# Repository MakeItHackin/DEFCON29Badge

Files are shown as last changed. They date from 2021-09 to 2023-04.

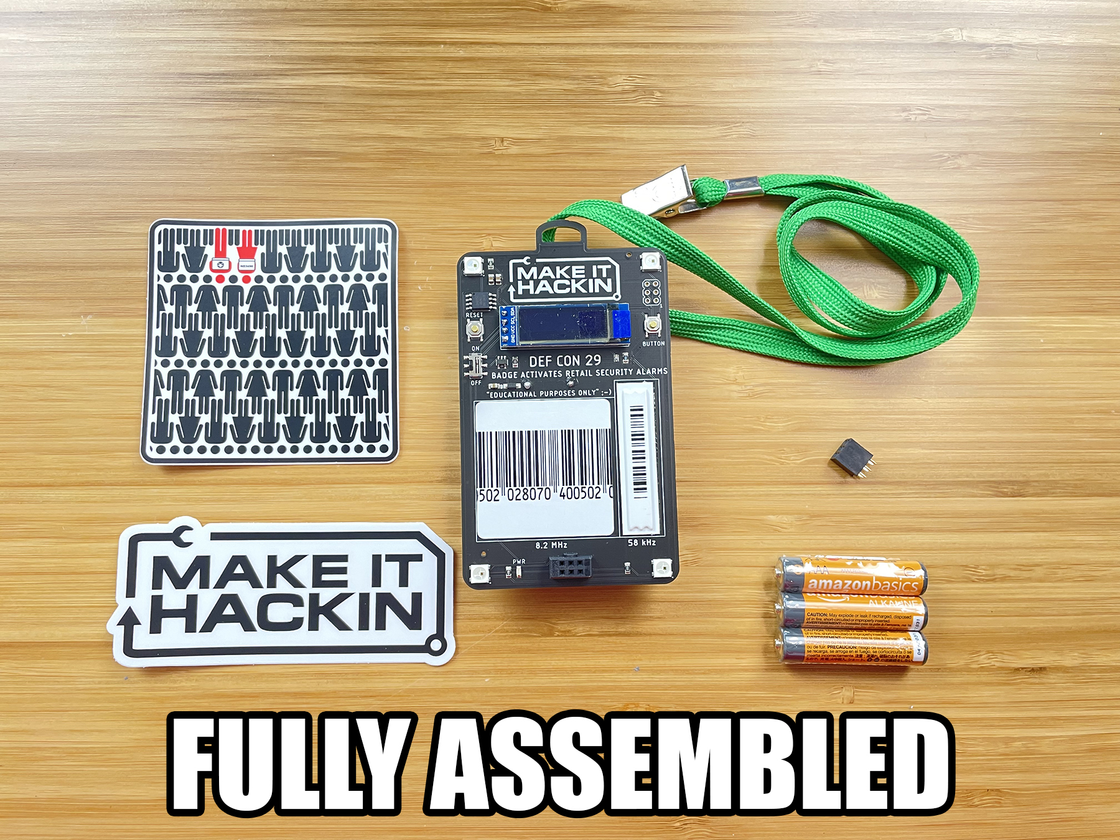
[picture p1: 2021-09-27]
Pictures/FullyAssembled/fa pic.jpg

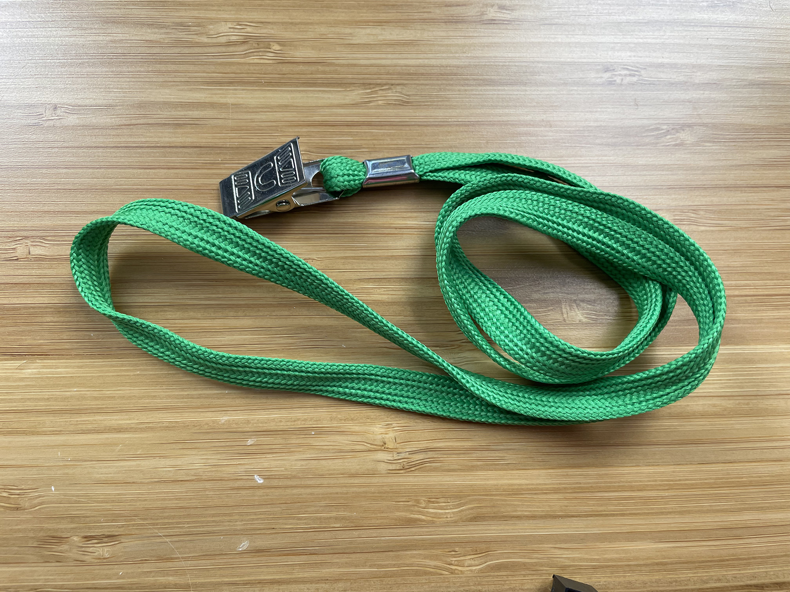
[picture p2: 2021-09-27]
Pictures/FullyAssembled/IMG_9313.jpeg

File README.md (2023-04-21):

# DC 29 Badge and SAO
==========================================================

Purchase Fully Assembled Badge or Kit Here:  
https://www.tindie.com/products/makeithackin/makeithackin-def-con-29-electronic-badge/

Unboxing, Reviewing, and Programming a Fully-Assembled Badge:  
https://youtu.be/G82_usjS0wA

Assembling the badge kit:  
https://youtu.be/OIYtvjFRpec

I'll update this readme as time goes on, but yeah... this is my first official MakeItHackin unoffical DEF CON badge.

Badges will feature an ATTiny85 Microcontroller, OLED Display, RGB LEDs, and a SAO connector for all your shitty add-ons.

They will also include two security tags (applied in those blank spots).  One is for Checkpoint systems (8.2 MHz) and one is for Sensormatic systems (58 kHz).  Take your badge into any retail store and set off their alarms!  (just kidding, don't do that.)

It was difficult to think of a shape for the outline and I wanted to get them ordered ASAP, so I made the badge in the shape of a credit card to relate to the retail security theme.  

Hack the Planet

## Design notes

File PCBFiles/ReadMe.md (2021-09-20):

These are the Gerber Files used to make the PCBs.  Make your own!
The Eagle files are also included (.sch and .brd) for the Badge and SAO

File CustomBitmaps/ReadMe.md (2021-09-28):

Here's how to create a custom Bitmap for your MakeItHackin Badge.  This requires you to reprogram your badge, so you'll need an AVR programmer and a way to upload the code (Arduino IDE can do it)

I briefly cover this process in the YouTube tutorial: https://youtu.be/G82_usjS0wA

Create a bitmap that is 128x32 pixels.  You can use the photoshop template in this folder, or rework one of the bitmaps included.  When I save the template as a bitmap in photoshop I use the following settings for bitmap: Windows / 24 bit.

Next, convert bitmap to code: https://javl.github.io/image2cpp/
Use the following settings:
Background color: black
Invert image colors: yes
Canvas size: 128x32
Code output format: Arduino
Draw mode: Vertical - 1 bit per pixel

Then copy the output code and paste it into the variable  "customBitmap", which looks like a big array of HEX.  It'll be the last one of these you see in the code.  Make sure to replace the previous code inside that variable.

Finally, change the variable "badgeType" to the value of 8.  This will tell the code to display the customBitmap screen.

That's it!

Enjoy!

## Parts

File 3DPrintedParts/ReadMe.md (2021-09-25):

I created some 3d printed parts to help me assemble hundreds of badges.  They are not necessary if you're building one or two badges, but helpful for multiple.  Maybe they'll give you some ideas as well.  They were designed in Fusion 360 and printed on a Prusa Mini+

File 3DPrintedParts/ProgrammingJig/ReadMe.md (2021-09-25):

These are parts I made for my Programming Jig.

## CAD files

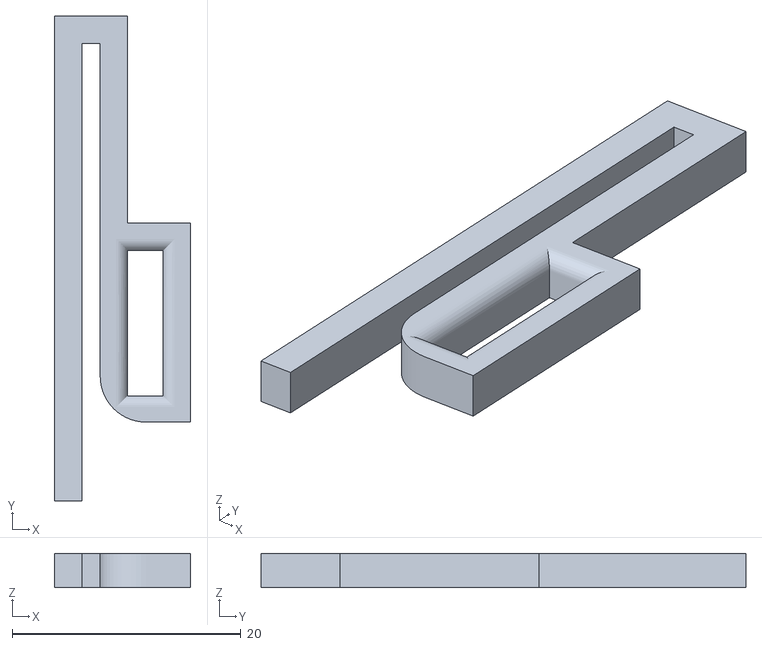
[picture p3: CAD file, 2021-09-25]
3DPrintedParts/OLEDSpacer v7.stl
11.9 x 42.4 x 3.00

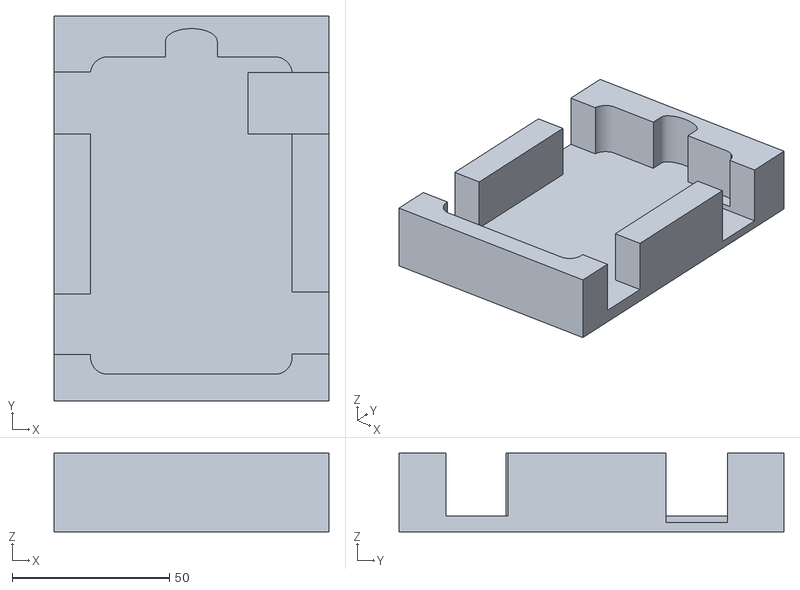
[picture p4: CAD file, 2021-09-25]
3DPrintedParts/ProgrammingJig/programmerJig_thickness1-5 v2.stl
87.5 x 122.6 x 25.0

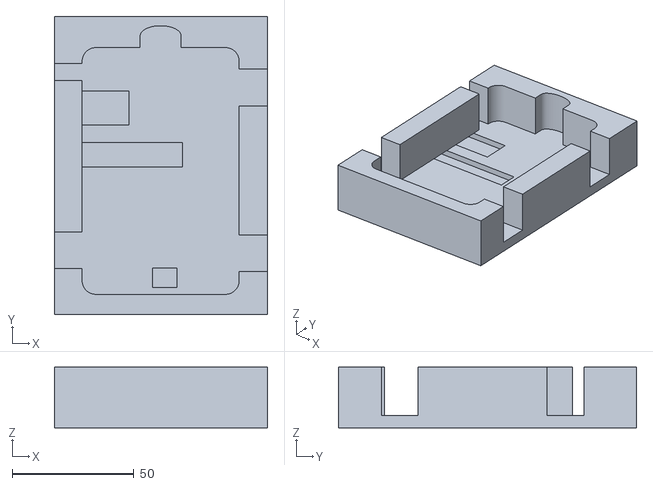
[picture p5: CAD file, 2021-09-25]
3DPrintedParts/TestingJig/testerJig_thickness2 v2.stl
87.5 x 122.6 x 25.0

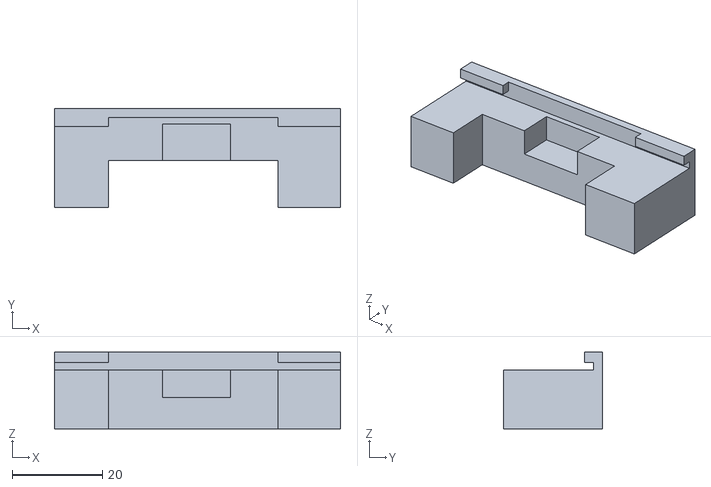
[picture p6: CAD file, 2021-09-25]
3DPrintedParts/BatterySpacer v6.stl
63.3 x 22.0 x 17.0

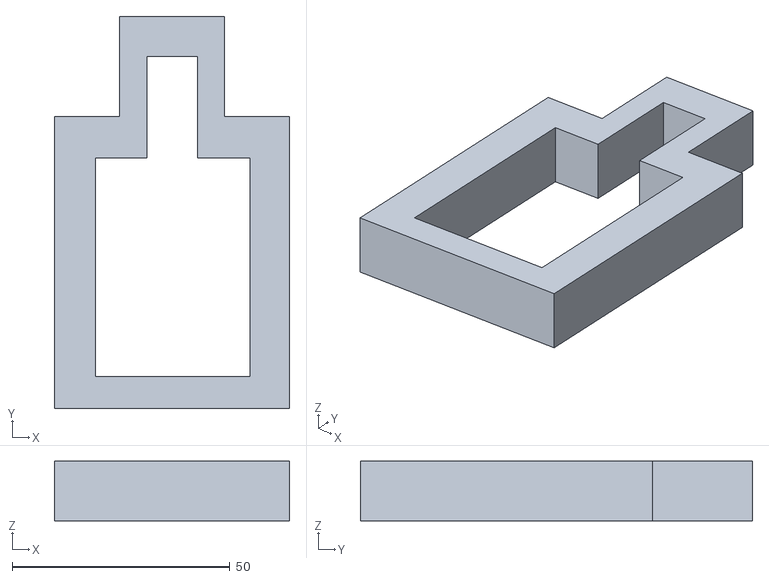
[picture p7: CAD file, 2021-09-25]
3DPrintedParts/ProgrammingJig/spacerv2 v1.stl
54.0 x 90.0 x 13.7

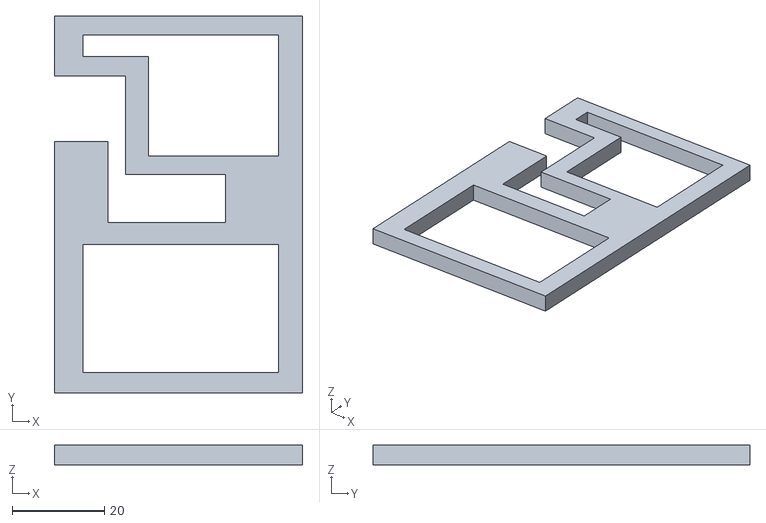
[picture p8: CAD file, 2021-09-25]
3DPrintedParts/TestingJig/testerJigSpacer v4.stl
53.9 x 81.8 x 4.30

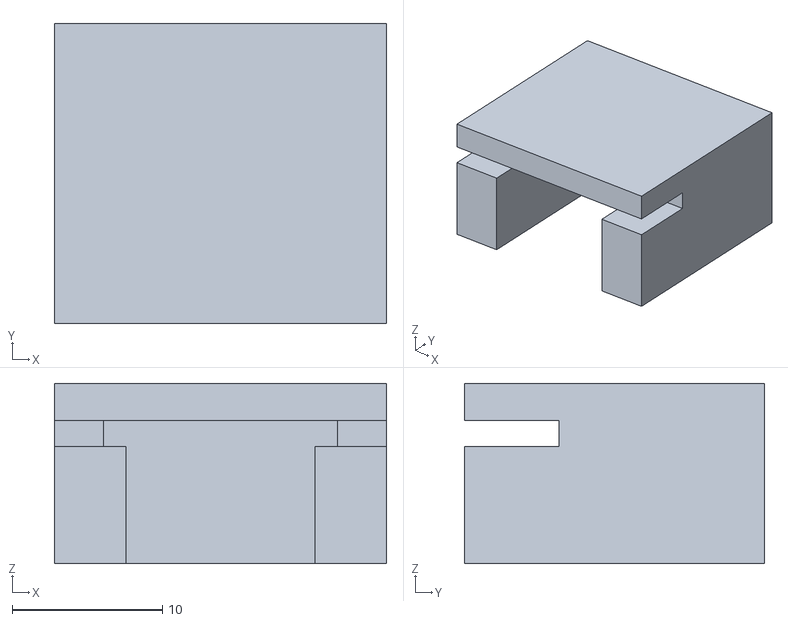
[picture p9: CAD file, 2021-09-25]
3DPrintedParts/SAOSpacer_TOP v6.stl
22.1 x 20.0 x 12.0

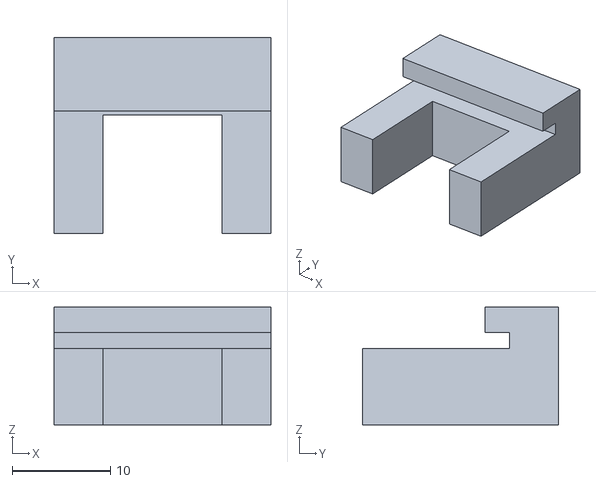
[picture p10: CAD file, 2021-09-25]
3DPrintedParts/SAOSpacer_redo v9.stl
22.1 x 20.0 x 12.0

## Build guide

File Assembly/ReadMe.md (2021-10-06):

Here are some files helpful for assembling the badge.  Watch the step-by-step video here:  https://youtu.be/OIYtvjFRpec

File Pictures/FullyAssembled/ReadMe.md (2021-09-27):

These are the pictures for the Fully Assembled Version

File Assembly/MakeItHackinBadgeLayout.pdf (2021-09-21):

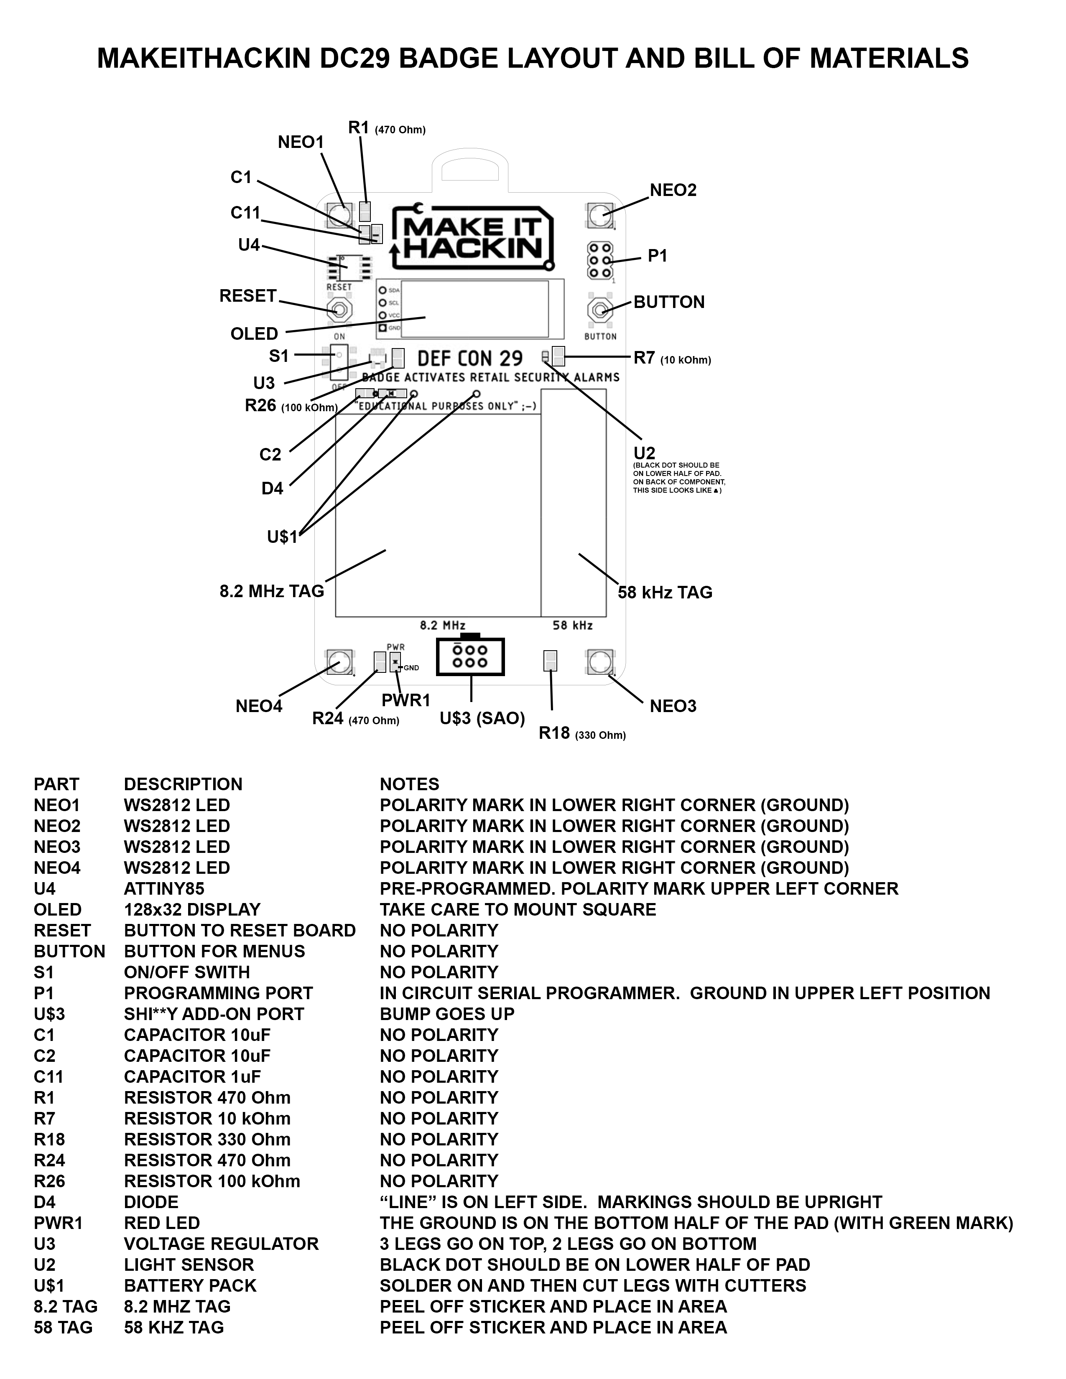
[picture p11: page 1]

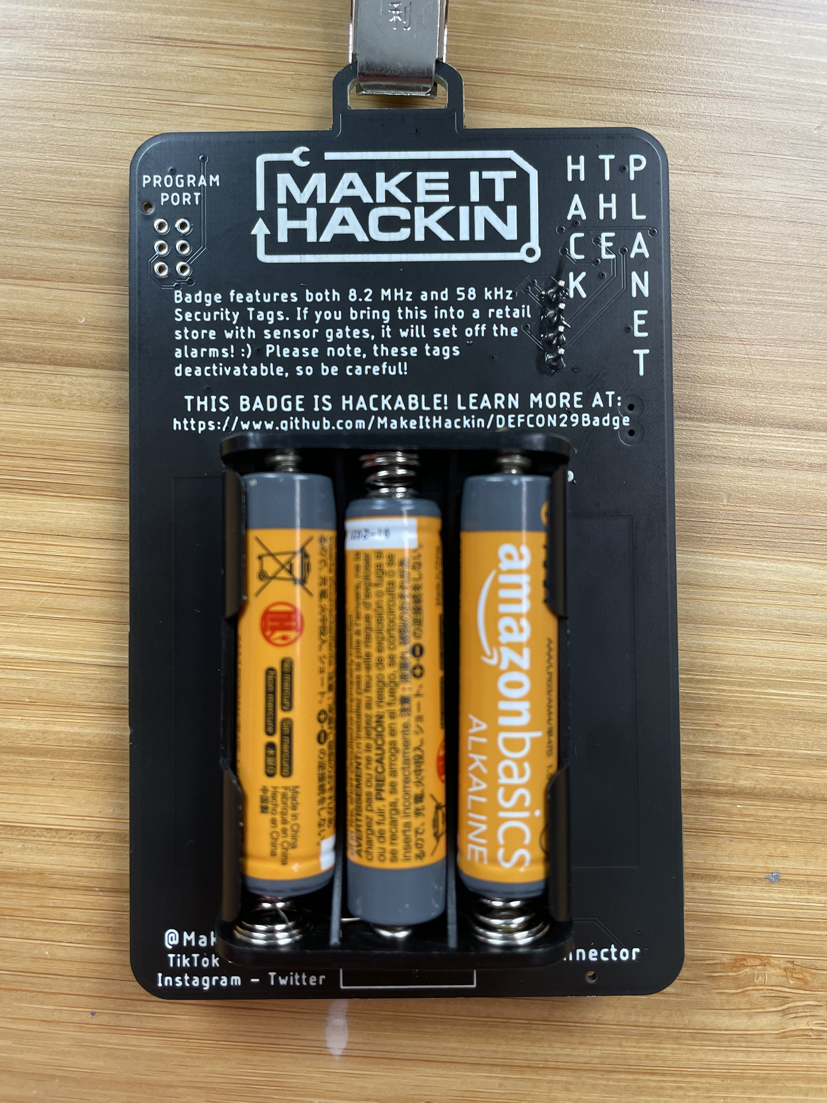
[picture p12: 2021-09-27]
Pictures/FullyAssembled/back.jpg

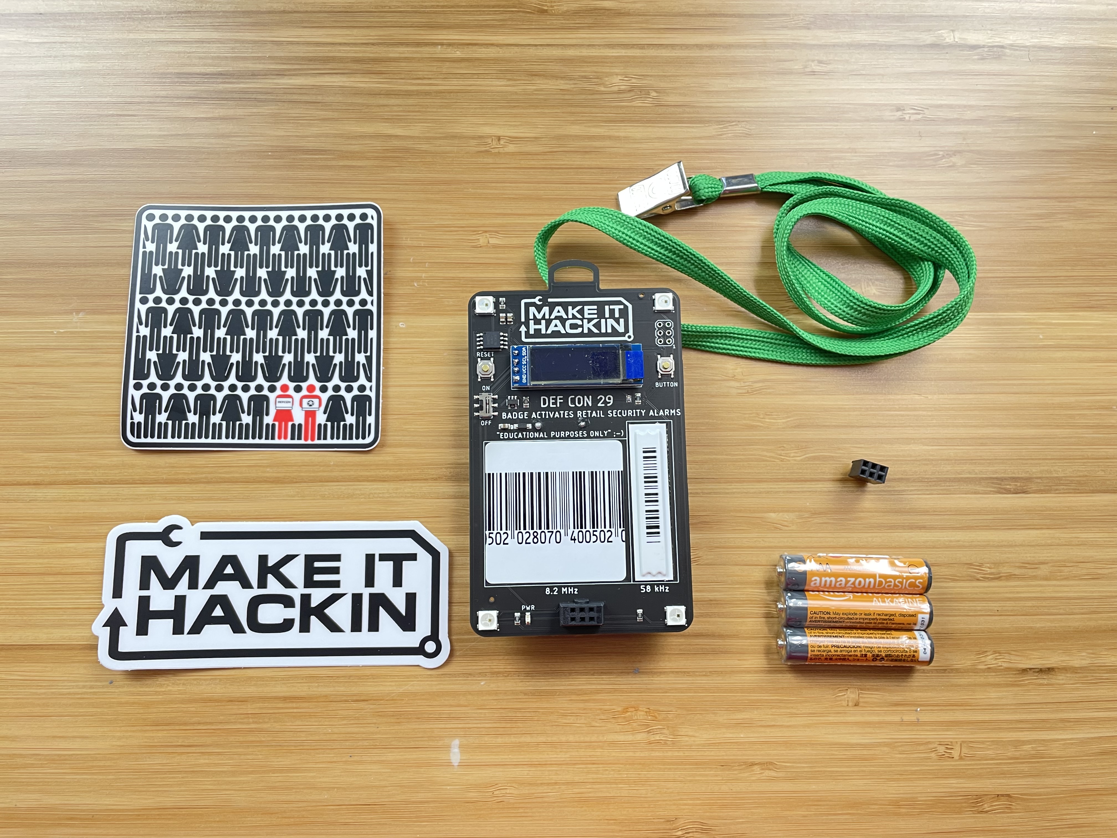
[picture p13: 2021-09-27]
Pictures/FullyAssembled/IMG_9314.jpeg

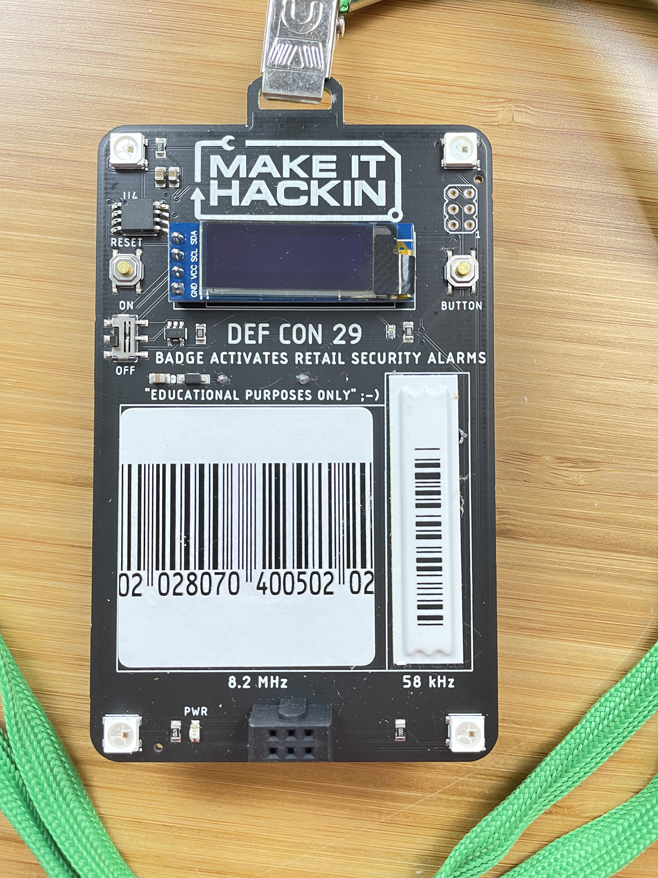
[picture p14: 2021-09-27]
Pictures/FullyAssembled/IMG_9297.jpeg

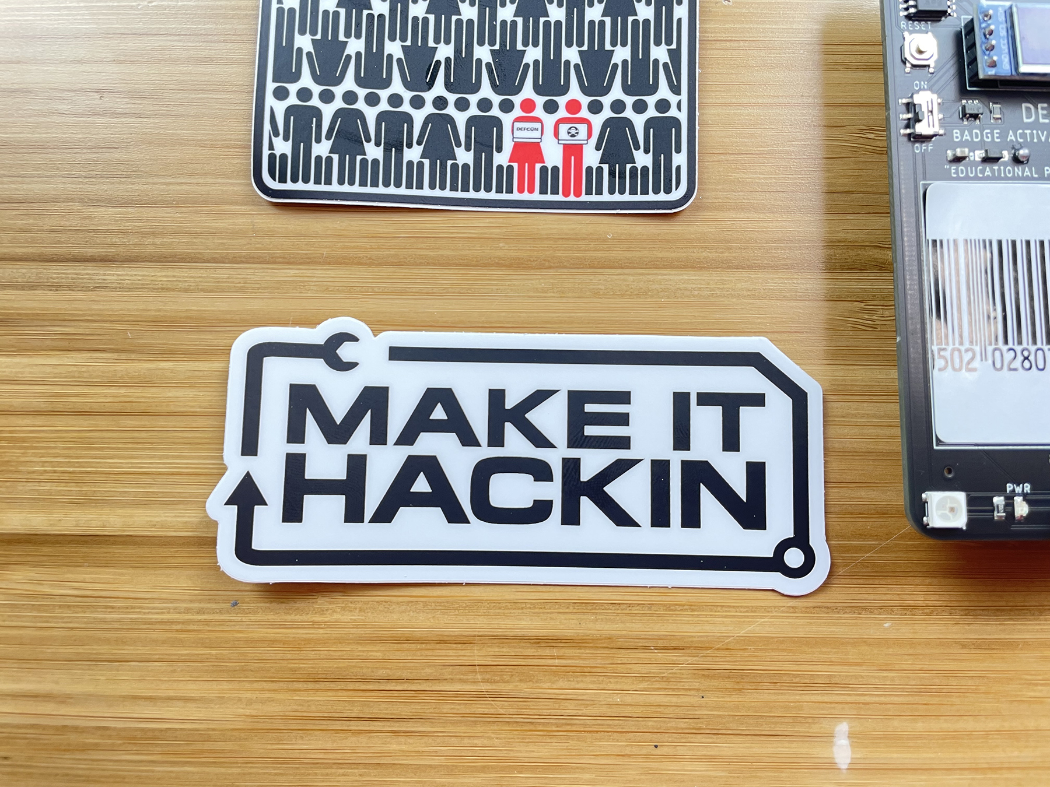
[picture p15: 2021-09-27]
Pictures/FullyAssembled/IMG_9316.jpeg

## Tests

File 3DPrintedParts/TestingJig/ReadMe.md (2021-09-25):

These are parts I printed for my Testing Jig

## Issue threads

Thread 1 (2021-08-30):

Code for IC

adradloff, 2021-08-30:
When will the code for the IC be posted?  I ordered the parts for my PCB I received and am starting to put it all together.  Thanks.

PS. hopefully I solder that ATTINY85-20MUR on properly,  that was a pita.

MakeItHackin, 2021-08-31:
haha... yup.  QFNs are not fun.  i havent commented a lot of the code yet, but i'll go ahead and put it up!  i might switch it out later with more comments, but the functionality "probably" will not change.

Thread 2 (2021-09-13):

schematic, and the markings on the PCB

g0Idfinger, 2021-09-13:
Do you have a schematic and marking as to which component goes where on the board?  The rest of my components should be in this weekend and I would love to get this put together.  Thanks for your help and creating this great badge!

MakeItHackin, 2021-09-14:
hey there, this info will be posted within the next two weeks when I prepare the instructions for the people who ordered the kits

MakeItHackin, 2021-09-20:
> Do you have a schematic and marking as to which component goes where on the board? The rest of my components should be in this weekend and I would love to get this put together. Thanks for your help and creating this great badge!

hey, i just uploaded schematic and board layouts to the "Assembly" folder

g0Idfinger, 2021-09-21:
Thanks, I got it together and the IC is programmed, the display comes up and says press button to test components, and does nothing, so I guess I have some testing to do.

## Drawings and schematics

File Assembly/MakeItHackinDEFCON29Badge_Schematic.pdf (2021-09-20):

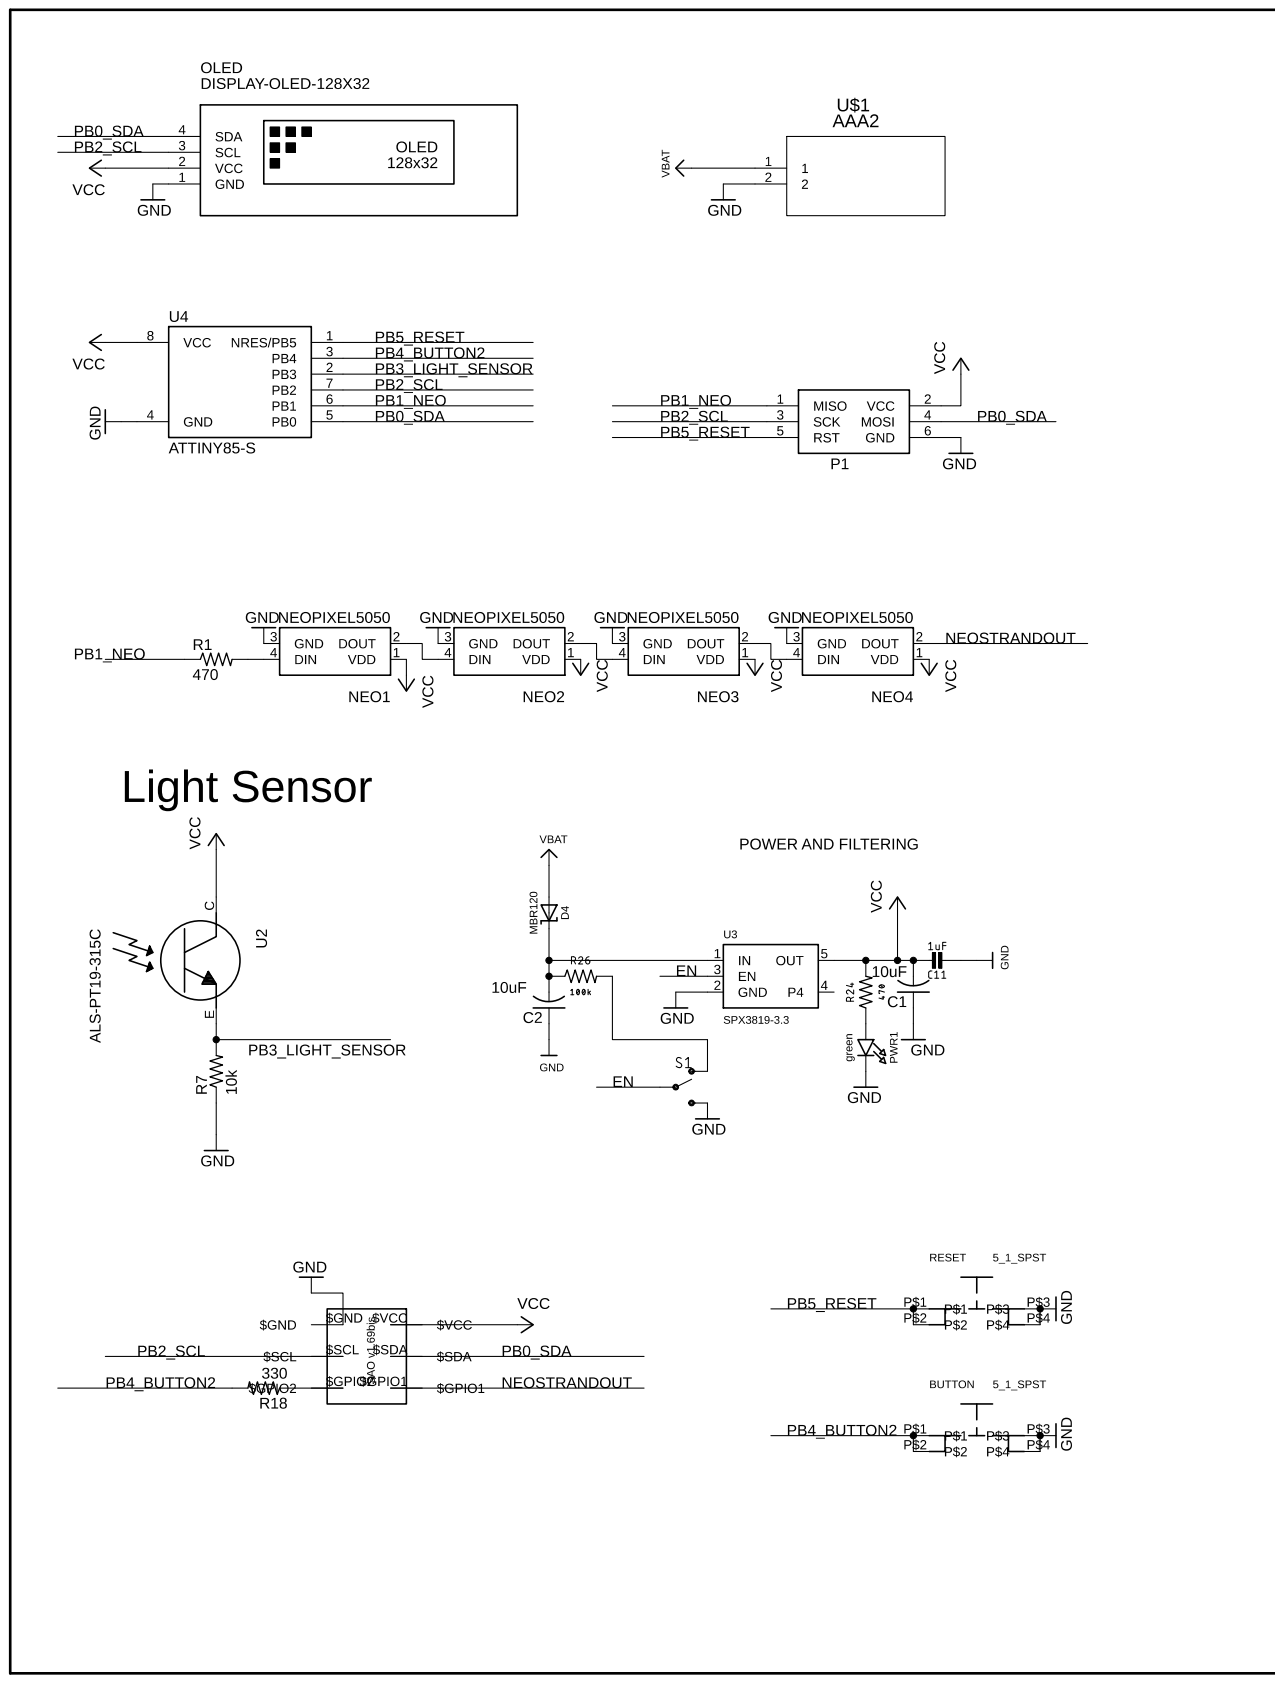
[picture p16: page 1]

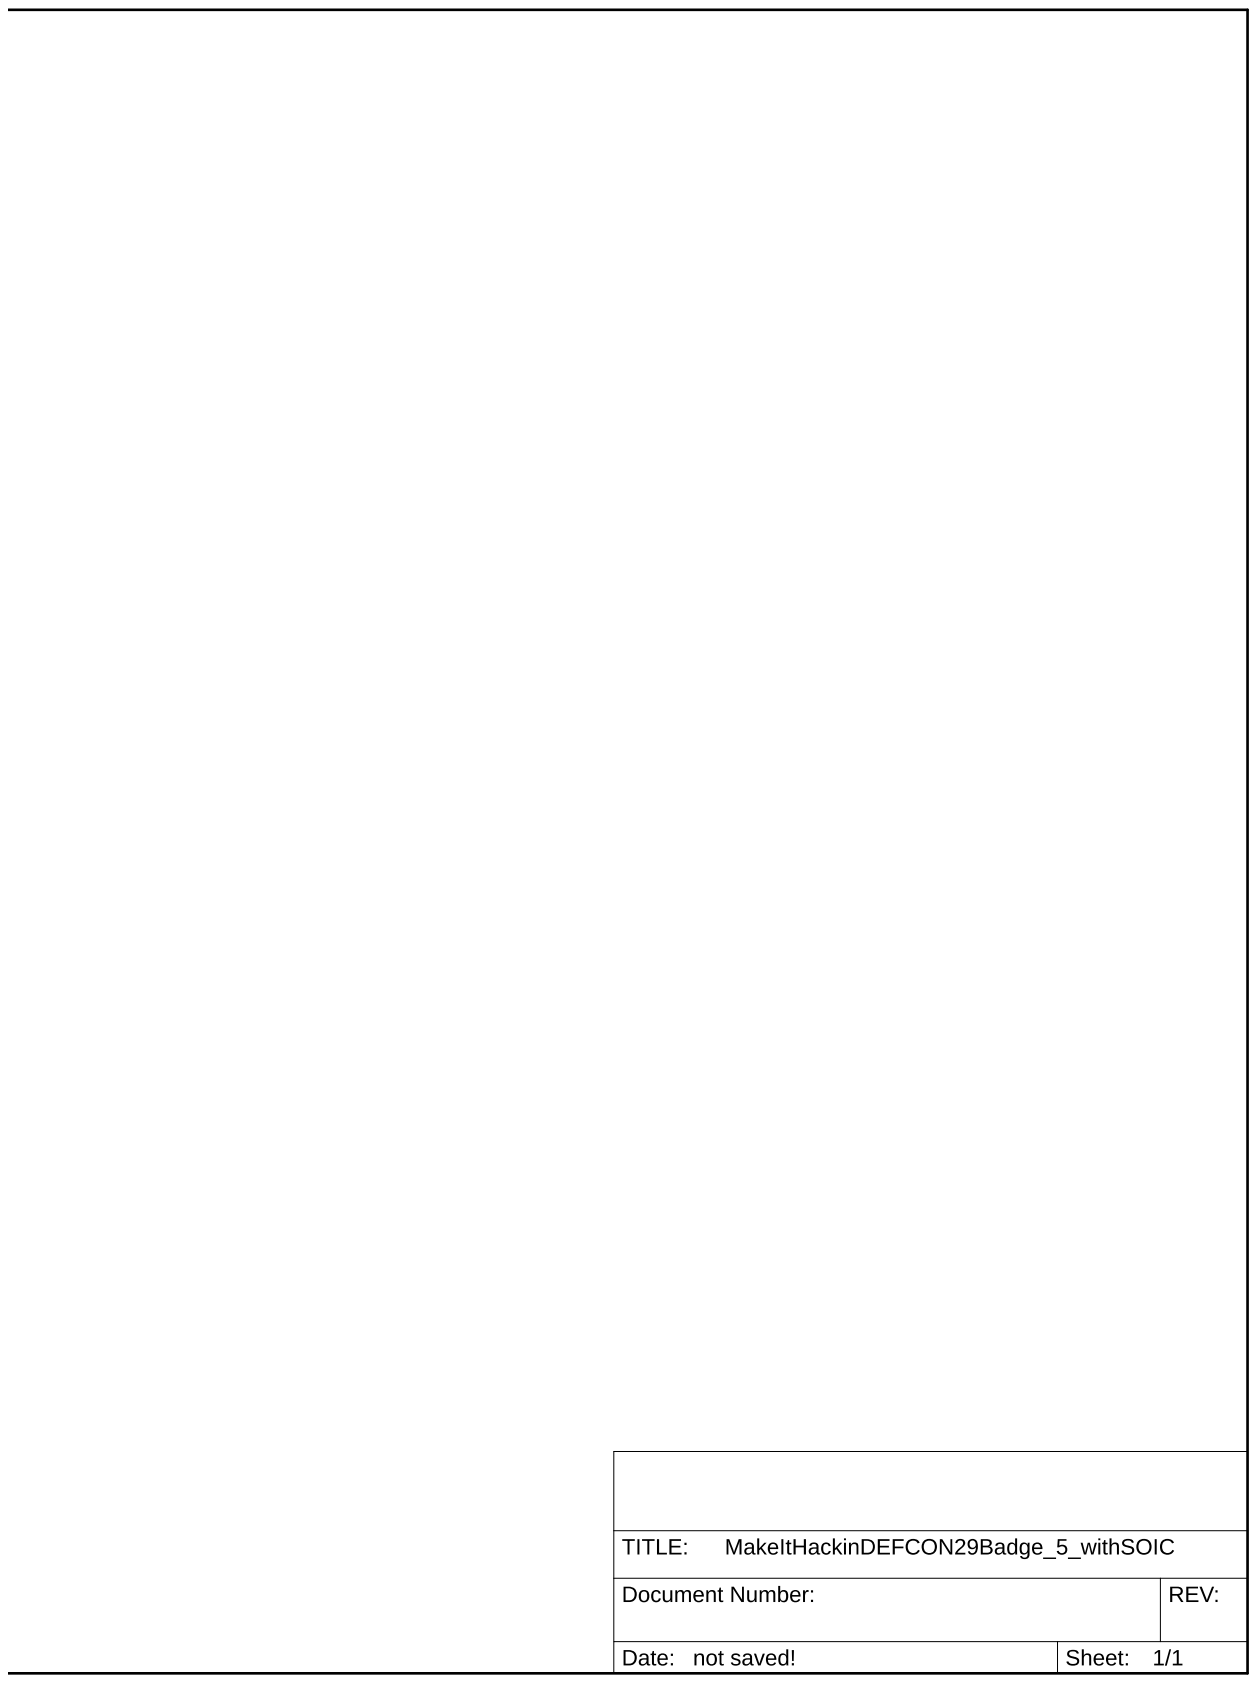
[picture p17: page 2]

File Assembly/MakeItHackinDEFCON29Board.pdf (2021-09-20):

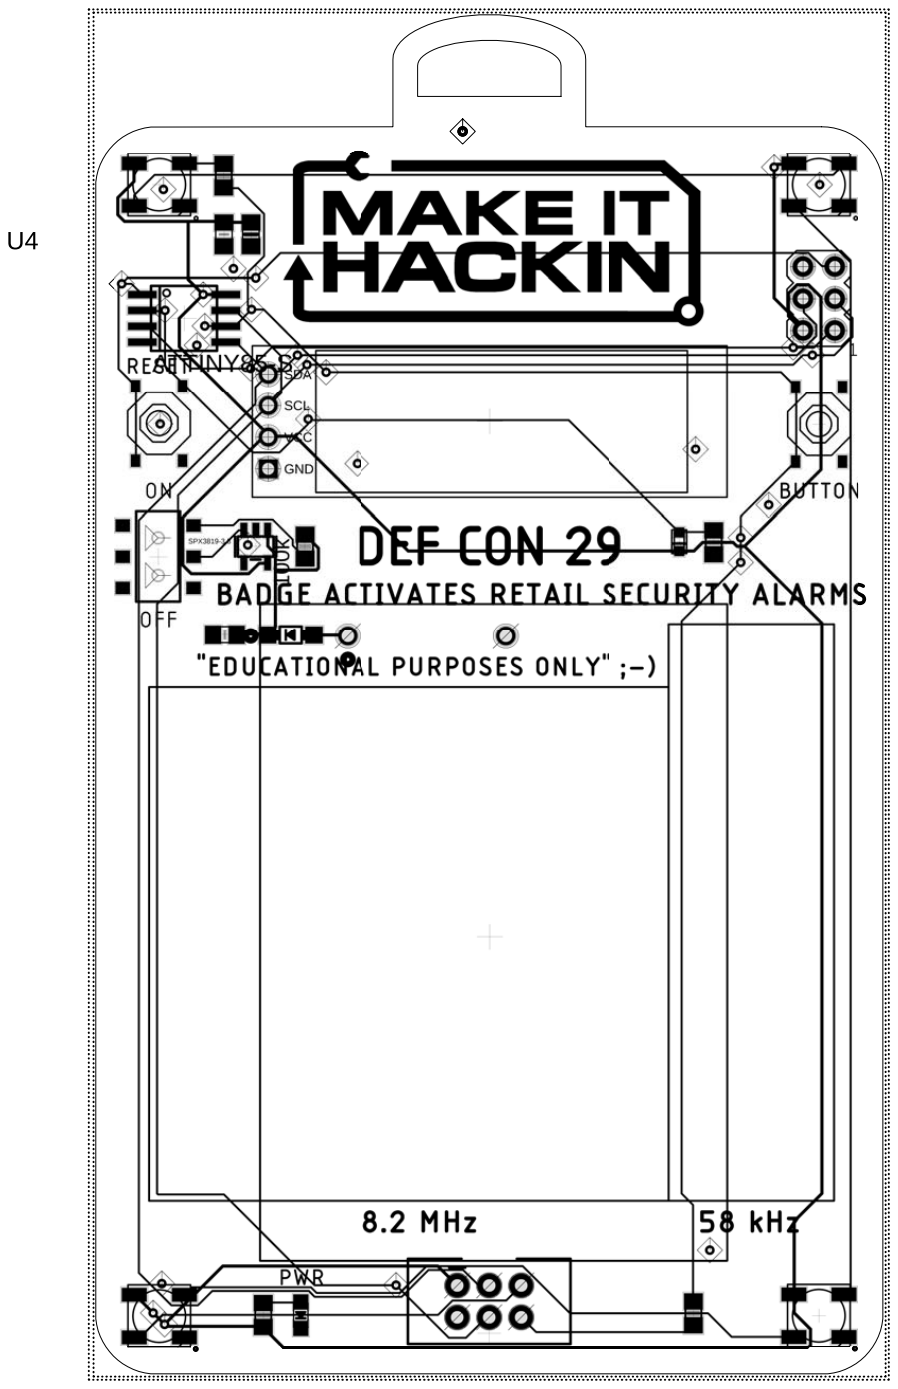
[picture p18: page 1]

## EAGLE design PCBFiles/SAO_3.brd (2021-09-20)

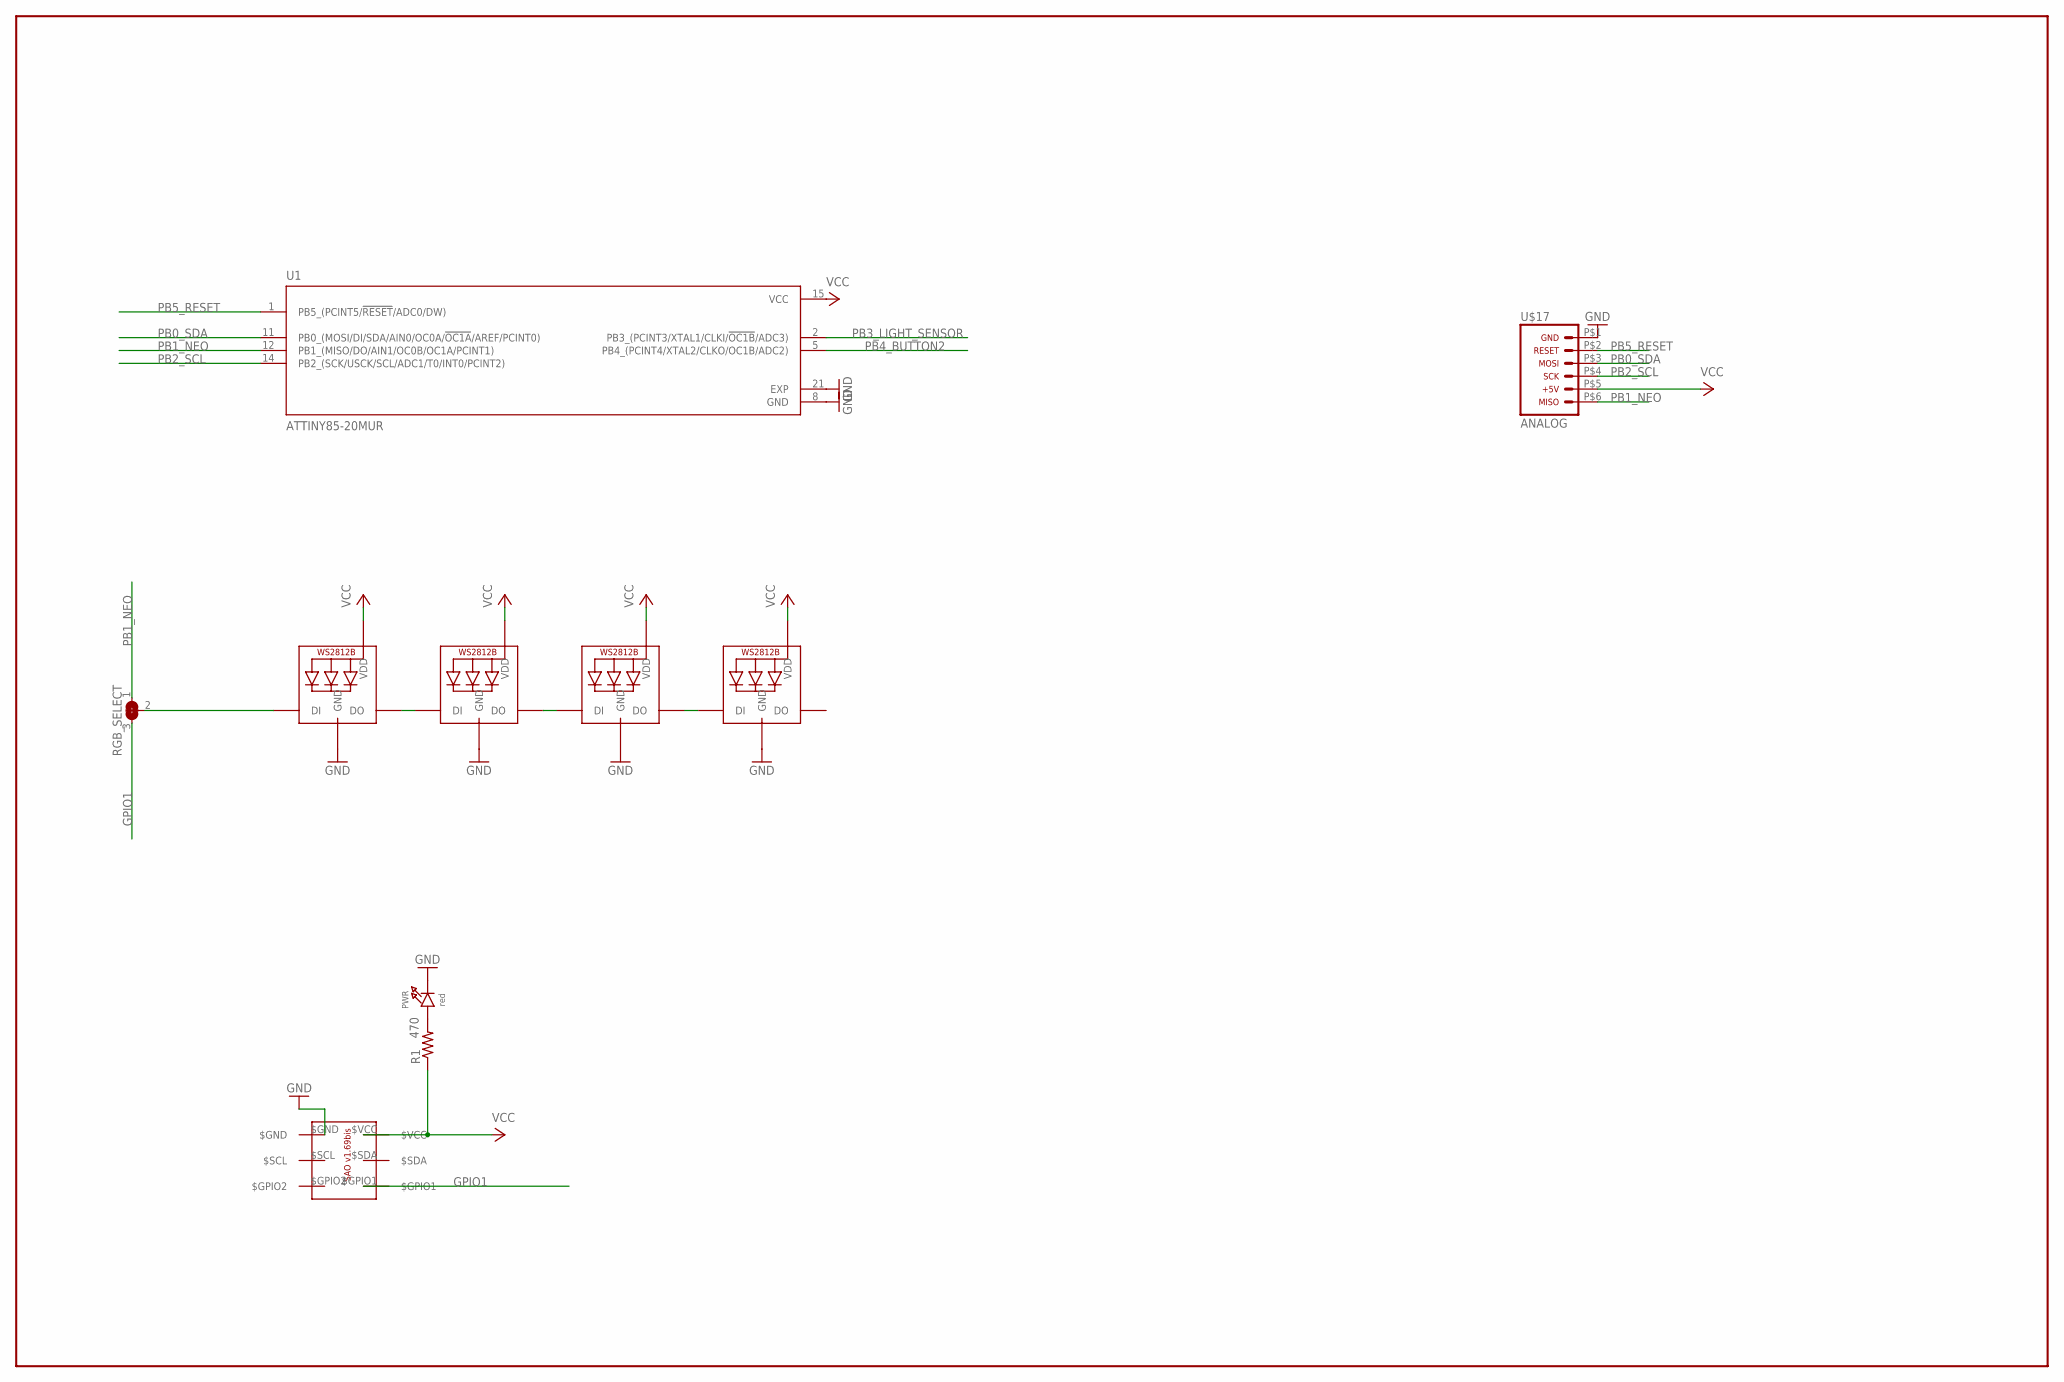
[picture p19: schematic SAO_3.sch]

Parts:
LED1, LED2, LED3, LED4: WS2812B3535; LED3535
PWR: red; CHIPLED_0805_NOOUTLINE
R1: 470; R0805
RGB_SELECT: SOLDERJUMPER_2WAY; SOLDERJUMPER_2WAY_OPEN_NOPASTE
U1: ATTINY85-20MUR; QFN50P400X400X80-21N
U$3: SAO-1.69; 2X3-SHROUDED-FEMALE
U$17: ICSP_FLATSMD_2X3; CONN-SMD-2X3

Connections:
GND: LED1.1 (GND), LED2.1 (GND), LED3.1 (GND), LED4.1 (GND), PWR.C, U1.8 (GND), U1.21 (EXP), U$3.$GND, U$17.P$1 (1)
GPIO1: RGB_SELECT.3, U$3.$GPIO1
unnamed: LED1.2 (DI), RGB_SELECT.2
unnamed: PWR.A, R1.2
unnamed: LED3.4 (DO), LED4.2 (DI)
unnamed: LED1.4 (DO), LED2.2 (DI)
unnamed: LED2.4 (DO), LED3.2 (DI)
PB0_SDA: U1.11 (PB0_(MOSI/DI/SDA/AIN0/OC0A/!OC1A!/AREF/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), U$17.P$3 (3)
PB1_NEO: RGB_SELECT.1, U1.12 (PB1_(MISO/DO/AIN1/OC0B/OC1A/PCINT1)), U$17.P$6 (6)
PB2_SCL: U1.14 (PB2_(SCK/USCK/SCL/ADC1/T0/INT0/PCINT2)), U$17.P$4 (4)
PB3_LIGHT_SENSOR: U1.2 (PB3_(PCINT3/XTAL1/CLKI/!OC1B!/ADC3))
PB4_BUTTON2: U1.5 (PB4_(PCINT4/XTAL2/CLKO/OC1B/ADC2))
PB5_RESET: U1.1 (PB5_(PCINT5/!RESET!/ADC0/DW)), U$17.P$2 (2)
VCC: LED1.3 (VDD), LED2.3 (VDD), LED3.3 (VDD), LED4.3 (VDD), R1.1, U1.15 (VCC), U$3.$VCC, U$17.P$5 (5)

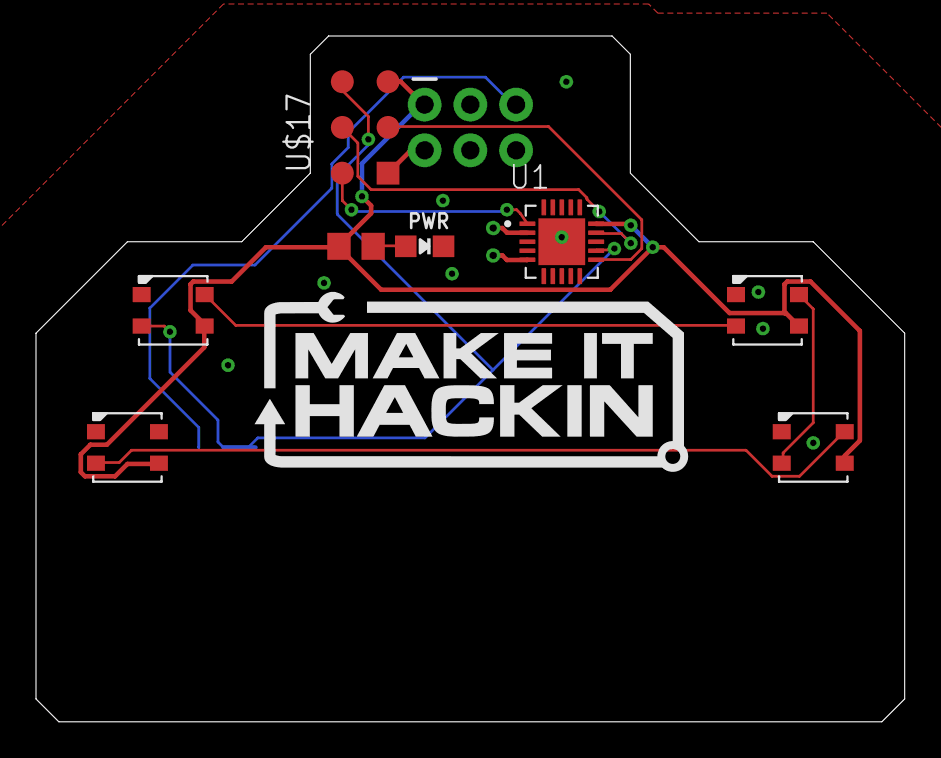
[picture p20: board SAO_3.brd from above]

Board: 2 copper layers, 48.3 x 38.1 mm, 10 parts (1 on the bottom side), 12 nets.

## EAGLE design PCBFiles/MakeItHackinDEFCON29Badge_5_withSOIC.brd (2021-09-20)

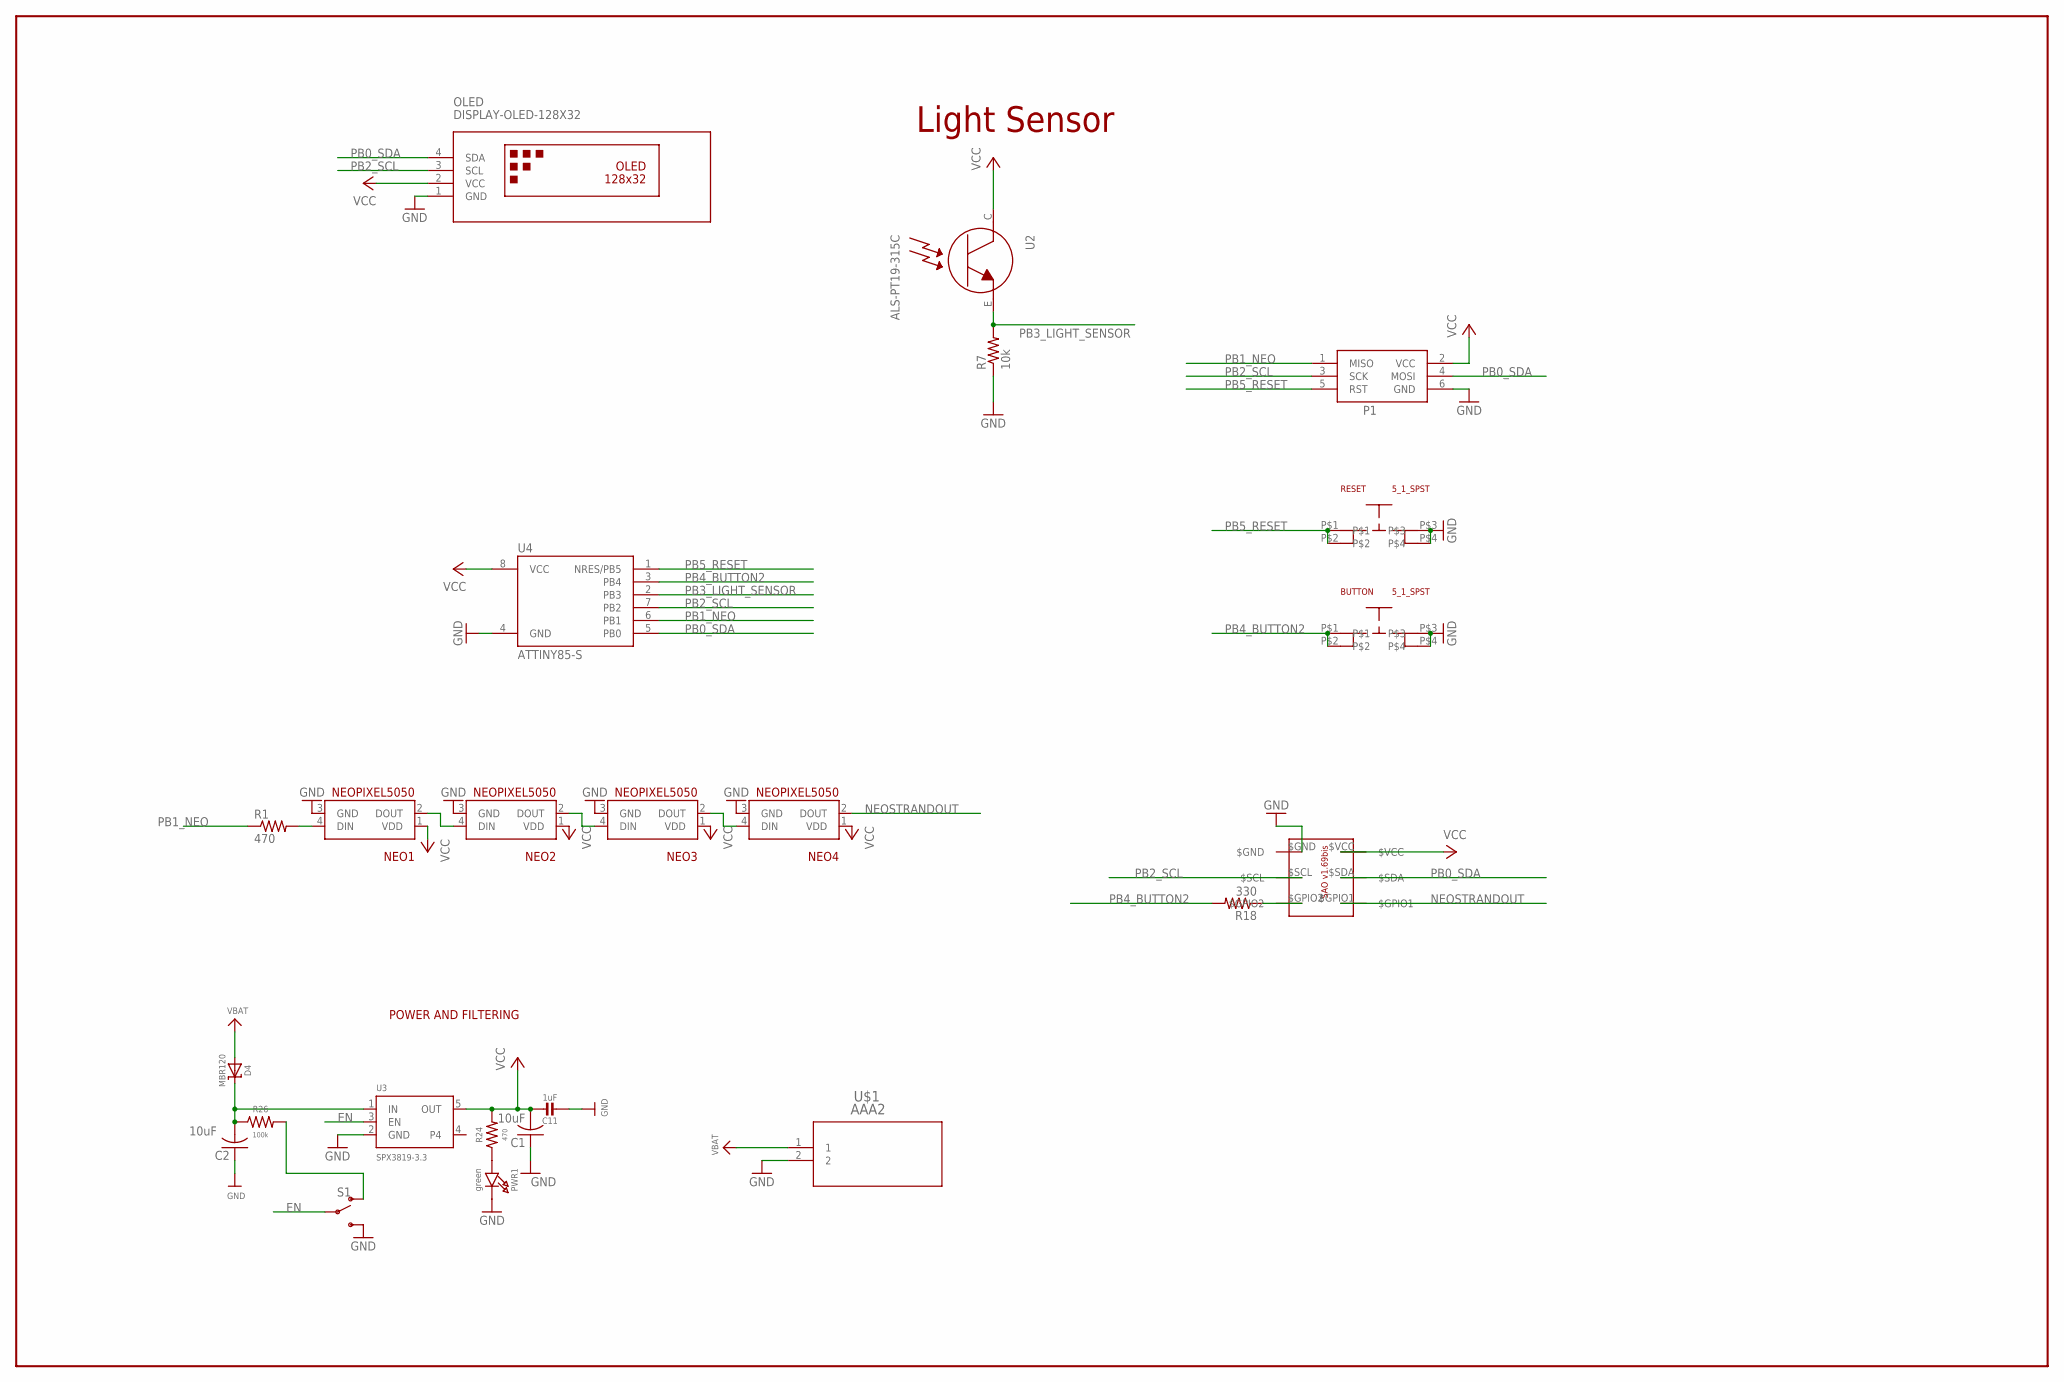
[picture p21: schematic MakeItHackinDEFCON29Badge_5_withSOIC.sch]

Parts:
BUTTON: 5_1_SPST
C1, C2: 10uF; C0805
C11: 1uF; 0805-NO@1
D4: MBR120; SOD-123
NEO1, NEO2, NEO3, NEO4: NEOPIXEL5050
OLED: DISPLAY-OLED-128X32
P1: AVRISP-6; AVRISP
PWR1: green; CHIPLED_0805_NOOUTLINE
R1, R24: 470; R0805
R7: 10k; R0805
R18: 330; R0805
R26: 100k; R0805
RESET: 5_1_SPST
S1: SWITCH-SPDT-SMD-AYZ0202; SWITCH_DPDT_SMD_AYZ0202
U2: ALS-PT19-315C
U3: SPX3819-3.3; SOT23-5
U4: ATTINY85-S; SOIC8_EIAJ_208MIL
U$1: AAA2
U$3: SAO-1.69; 2X3-SHROUDED-FEMALE

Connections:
EN: S1.2, U3.3 (EN)
GND: BUTTON.P$3, BUTTON.P$4, C1.1, C2.1, C11.2, NEO1.3 (GND), NEO2.3 (GND), NEO3.3 (GND), NEO4.3 (GND), OLED.1 (GND), P1.6 (GND), PWR1.C, R7.1, RESET.P$3, RESET.P$4, S1.3 (S), U3.2 (GND), U4.4 (GND), U$1.2, U$3.$GND
unnamed: C2.2, D4.C, R26.1, U3.1 (IN)
unnamed: R18.1, U$3.$GPIO2
unnamed: PWR1.A, R24.1
unnamed: R26.2, S1.1 (O)
unnamed: NEO1.4 (DIN), R1.2
unnamed: NEO1.2 (DOUT), NEO2.4 (DIN)
unnamed: NEO2.2 (DOUT), NEO3.4 (DIN)
unnamed: NEO3.2 (DOUT), NEO4.4 (DIN)
NEOSTRANDOUT: NEO4.2 (DOUT), U$3.$GPIO1
PB0_SDA: OLED.4 (SDA), P1.4 (MOSI), U4.5 (PB0), U$3.$SDA
PB1_NEO: P1.1 (MISO), R1.1, U4.6 (PB1)
PB2_SCL: OLED.3 (SCL), P1.3 (SCK), U4.7 (PB2), U$3.$SCL
PB3_LIGHT_SENSOR: R7.2, U2.E, U4.2 (PB3)
PB4_BUTTON2: BUTTON.P$1, BUTTON.P$2, R18.2, U4.3 (PB4)
PB5_RESET: P1.5 (RST), RESET.P$1, RESET.P$2, U4.1 (NRES/PB5)
VBAT: D4.A, U$1.1
VCC: C1.2, C11.1, NEO1.1 (VDD), NEO2.1 (VDD), NEO3.1 (VDD), NEO4.1 (VDD), OLED.2 (VCC), P1.2 (VCC), R24.2, U2.C, U3.5 (OUT), U4.8 (VCC), U$3.$VCC

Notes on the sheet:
Light Sensor
POWER AND FILTERING

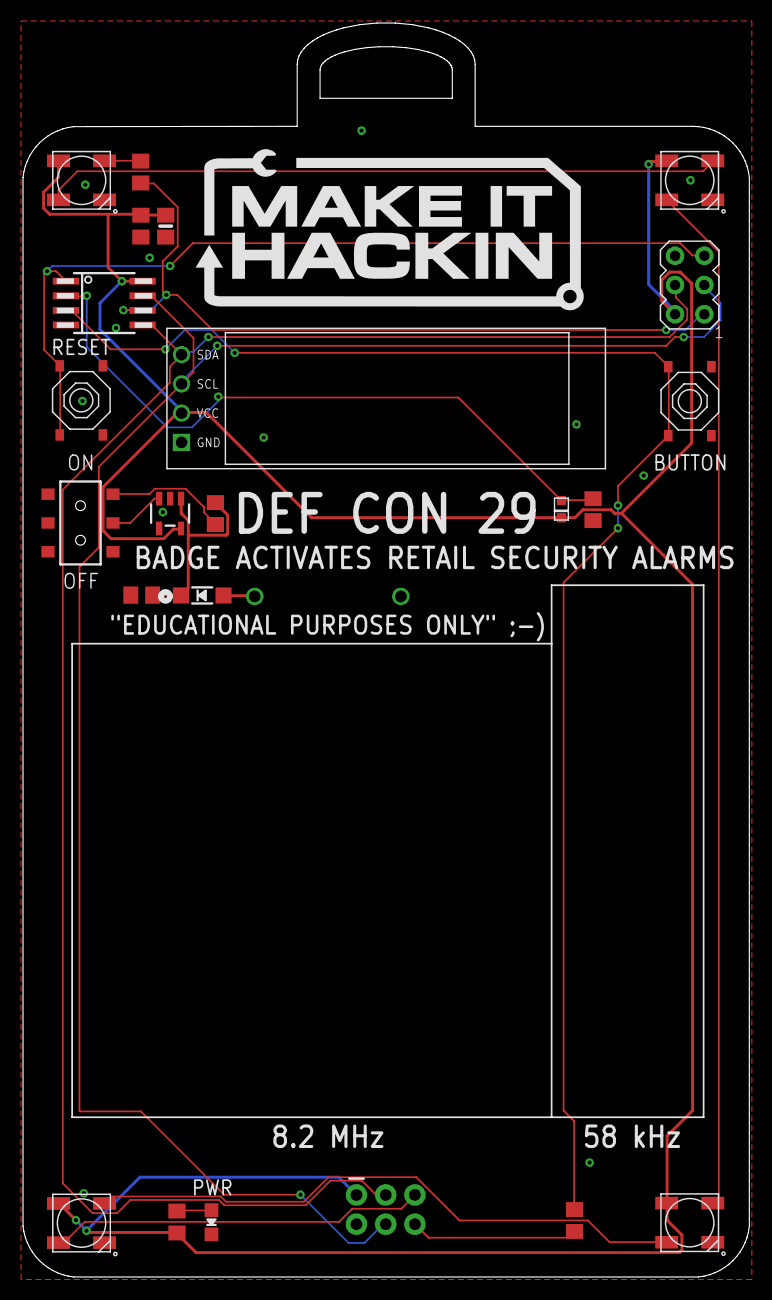
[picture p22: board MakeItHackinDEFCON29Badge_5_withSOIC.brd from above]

Board: 2 copper layers, 63.1 x 109.0 mm, 24 parts (1 on the bottom side), 19 nets.

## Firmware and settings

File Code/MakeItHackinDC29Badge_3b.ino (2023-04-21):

//////////////////////////////////////////////////////////////////////////////////////////////////
//////////  2021 MakeItHackin DEF CON 29 Badge - DEMO CODE 
//////////////////////////////////////////////////////////////////////////////////////////////////


/* 
  IF YOU HAVE ANY QUESTIONS OR COMMENTS, FEEL FREE TO INITIATE AN ISSUE ON GITHUB.  I PLAN TO ADD ADDITIONAL COMMENTS IN THE CODE, AND MAYBE SOME MORE FEATURES!
  
  ALL LIBRARIES FOR COMPONENTS WILL BE INCLUDED IN GITHUB LINK, SO FEEL FREE TO TINKER AROUND!
  https://github.com/MakeItHackin/DEFCON29Badge/

  Create output code for bitmaps:  https://javl.github.io/image2cpp/
  Background color: black
  Invert image colors: yes
  Canvas size: 128x32
  Code output format: Arduino
  Draw mode: Vertical - 1 bit per pixel
  
 */




/*

  LIBRARIES FOR NEOPIXELS WERE DERIVED FROM LIBRARIES BY ADAFRUIT

  Adafruit invests time and resources providing this open source code,
  please support Adafruit and open-source hardware by purchasing
  products from Adafruit!
  Written by Limor Fried/Ladyada for Adafruit Industries.
  MIT license, all text above must be included in any redistribution
  
 */


////////////////////////////////////////////////////////////////
//////////  ATTINY 85 PINOUT
////////////////////////////////////////////////////////////////

 
/*
  
  GND - BATTERY NEGATIVE TERMINAL
  VCC - BATTERY POSITIVE TERMINAL
  PBO - I2C BUS - SDA
  PB1 - NEOPIXEL OUT
  PB2 - I2C BUS - SCL
  PB3 - LIGHT SENSOR INPUT
  PB4 - BUTTON INPUT
  PB5 - RESET BUTTON
  
 */


////////////////////////////////////////////////////////////////
//////////  VARIABLES AND LIBRARIES
////////////////////////////////////////////////////////////////

#include "TinyWireM.h" // USED FOR I2C CAPABILITIES
#include "TinyOzOLED.h" // USED FOR THE SSD1306 OLED SCREEN

#include <tinyNeoPixel_Static.h>  // USED FOR NEOPIXELS
#define PIN 1
// Parameter 1 = number of pixels in strip
// Parameter 2 = Arduino pin number (most are valid)
// Parameter 3 = pixel type flags, add together as needed:
//   NEO_GRB     Pixels are wired for GRB bitstream (most NeoPixel products)
//   NEO_RGB     Pixels are wired for RGB bitstream (v1 FLORA pixels, not v2)
// Parameter 4 = array to store pixel data in      
#define NUMPIXELS 14  // There are Four on the Badge... and allowing 10 more for SAOs
// Since this is for the static version of the library, we need to supply the pixel array
// This saves space by eliminating use of malloc() and free(), and makes the RAM used for
// the frame buffer show up when the sketch is compiled.
byte pixels[NUMPIXELS * 3];
// When we setup the NeoPixel library, we tell it how many pixels, and which pin to use to send signals.
// Note that for older NeoPixel strips you might need to change the third parameter--see the strandtest
// example for more information on possible values. Finally, for the 4th argument we pass the array we
// defined above.
tinyNeoPixel strip = tinyNeoPixel(NUMPIXELS, PIN, NEO_GRB, pixels);
// IMPORTANT: To reduce NeoPixel burnout risk, add 1000 uF capacitor across
// pixel power leads, add 300 - 500 Ohm resistor on first pixel's data input
// and minimize distance between Arduino and first pixel.  Avoid connecting
// on a live circuit...if you must, connect GND first.


#define BUTTON_PIN   4    // Digital IO pin connected to the button.  This will be
                          // driven with a pull-up resistor so the switch should
                          // pull the pin to ground momentarily.  On a high -> low
                          // transition the button press logic will execute.

                          

#define LIGHT_SENSOR_PIN A3  // THIS IS PB3, BUT MUST LABEL IT A3 IN ORDER FOR THE ANALOG FUNCTIONS TO WORK
int lightSensorValue = 0;

// 'makeithackin', 128x32px
const unsigned char MakeItHackinBitmap [] PROGMEM = { //MakeItHackin
  0x00, 0x00, 0x00, 0x00, 0x00, 0x00, 0x00, 0x00, 0x00, 0x00, 0x00, 0x00, 0x00, 0x00, 0x00, 0x00, 
  0x00, 0x00, 0x00, 0x00, 0x00, 0x00, 0x00, 0x00, 0x00, 0x00, 0x00, 0x00, 0x00, 0x00, 0xf0, 0xf8, 
  0x18, 0x18, 0x1c, 0x1c, 0x1c, 0x1c, 0x1c, 0x1c, 0x3e, 0x36, 0x22, 0x00, 0x00, 0x00, 0x00, 0x1c, 
  0x1c, 0x1c, 0x1c, 0x1c, 0x1c, 0x1c, 0x1c, 0x1c, 0x1c, 0x1c, 0x1c, 0x1c, 0x1c, 0x1c, 0x1c, 0x1c, 
  0x1c, 0x1c, 0x1c, 0x1c, 0x1c, 0x1c, 0x1c, 0x1c, 0x1c, 0x1c, 0x1c, 0x1c, 0x1c, 0x1c, 0x1c, 0x1c, 
  0x1c, 0x1c, 0x1c, 0x1c, 0x1c, 0x1c, 0x1c, 0x1c, 0x1c, 0x1c, 0x1c, 0x1c, 0x38, 0x70, 0xe0, 0xc0, 
  0x80, 0x00, 0x00, 0x00, 0x00, 0x00, 0x00, 0x00, 0x00, 0x00, 0x00, 0x00, 0x00, 0x00, 0x00, 0x00, 
  0x00, 0x00, 0x00, 0x00, 0x00, 0x00, 0x00, 0x00, 0x00, 0x00, 0x00, 0x00, 0x00, 0x00, 0x00, 0x00, 
  0x00, 0x00, 0x00, 0x00, 0x00, 0x00, 0x00, 0x00, 0x00, 0x00, 0x00, 0x00, 0x00, 0x00, 0x00, 0x00, 
  0x00, 0x00, 0x00, 0x00, 0x00, 0x00, 0x00, 0x00, 0x00, 0x00, 0x00, 0x00, 0x00, 0x00, 0xff, 0xff, 
  0x00, 0x00, 0x00, 0x7f, 0x7f, 0x7f, 0x0f, 0x3e, 0x78, 0x70, 0x7c, 0x1e, 0x07, 0x7f, 0x7f, 0x00, 
  0x60, 0x78, 0x7c, 0x1f, 0x1f, 0x1b, 0x1f, 0x3e, 0x78, 0x60, 0x00, 0x7f, 0x7f, 0x0c, 0x1e, 0x3e, 
  0x73, 0x63, 0x41, 0x00, 0x00, 0x7f, 0x7f, 0x6d, 0x6d, 0x6d, 0x6d, 0x6d, 0x00, 0x00, 0x00, 0x00, 
  0x00, 0x7f, 0x7f, 0x7f, 0x01, 0x03, 0x03, 0x7f, 0x7f, 0x03, 0x03, 0x03, 0x00, 0x00, 0x00, 0xff, 
  0xff, 0x00, 0x00, 0x00, 0x00, 0x00, 0x00, 0x00, 0x00, 0x00, 0x00, 0x00, 0x00, 0x00, 0x00, 0x00, 
  0x00, 0x00, 0x00, 0x00, 0x00, 0x00, 0x00, 0x00, 0x00, 0x00, 0x00, 0x00, 0x00, 0x00, 0x00, 0x00, 
  0x00, 0x00, 0x00, 0x00, 0x00, 0x00, 0x00, 0x00, 0x00, 0x00, 0x00, 0x00, 0x00, 0x00, 0x00, 0x00, 
  0x00, 0x00, 0x00, 0x00, 0x00, 0x00, 0x00, 0x00, 0x00, 0x00, 0x00, 0x00, 0x00, 0x20, 0xf0, 0xfd, 
  0x70, 0x20, 0x00, 0xff, 0xff, 0xff, 0x18, 0x18, 0x18, 0x18, 0xff, 0xff, 0xff, 0x00, 0xc0, 0xf0, 
  0x7c, 0x7f, 0x7f, 0x77, 0x7f, 0x7e, 0xf8, 0xe0, 0x80, 0x7e, 0xff, 0xff, 0xc3, 0xc3, 0xc3, 0xc3, 
  0xc7, 0xe7, 0xe6, 0x00, 0xff, 0xff, 0x1c, 0x1c, 0x3c, 0x7e, 0xe7, 0xc3, 0x81, 0x01, 0x00, 0xff, 
  0xff, 0x00, 0xff, 0xff, 0xff, 0x0f, 0x1e, 0x3c, 0x78, 0xf0, 0xff, 0xff, 0x00, 0x00, 0x00, 0xff, 
  0xff, 0x00, 0x00, 0x00, 0x00, 0x00, 0x00, 0x00, 0x00, 0x00, 0x00, 0x00, 0x00, 0x00, 0x00, 0x00, 
  0x00, 0x00, 0x00, 0x00, 0x00, 0x00, 0x00, 0x00, 0x00, 0x00, 0x00, 0x00, 0x00, 0x00, 0x00, 0x00, 
  0x00, 0x00, 0x00, 0x00, 0x00, 0x00, 0x00, 0x00, 0x00, 0x00, 0x00, 0x00, 0x00, 0x00, 0x00, 0x00, 
  0x00, 0x00, 0x00, 0x00, 0x00, 0x00, 0x00, 0x00, 0x00, 0x00, 0x00, 0x00, 0x00, 0x00, 0x0f, 0x1f, 
  0x18, 0x18, 0x18, 0x18, 0x18, 0x18, 0x18, 0x18, 0x18, 0x18, 0x18, 0x18, 0x18, 0x18, 0x18, 0x18, 
  0x18, 0x18, 0x18, 0x18, 0x18, 0x18, 0x18, 0x18, 0x18, 0x18, 0x18, 0x18, 0x18, 0x18, 0x18, 0x18, 
  0x18, 0x18, 0x18, 0x18, 0x18, 0x18, 0x18, 0x18, 0x18, 0x18, 0x18, 0x18, 0x18, 0x18, 0x18, 0x18, 
  0x18, 0x18, 0x18, 0x18, 0x18, 0x18, 0x18, 0x18, 0x18, 0x18, 0x18, 0x18, 0x18, 0x1c, 0x3e, 0x23, 
  0x37, 0x1c, 0x00, 0x00, 0x00, 0x00, 0x00, 0x00, 0x00, 0x00, 0x00, 0x00, 0x00, 0x00, 0x00, 0x00, 
  0x00, 0x00, 0x00, 0x00, 0x00, 0x00, 0x00, 0x00, 0x00, 0x00, 0x00, 0x00, 0x00, 0x00, 0x00, 0x00
};

// 'hackthisbadge', 128x32px
const unsigned char hackThisBadgeBitmap [] PROGMEM = {
  0x00, 0x00, 0x00, 0x00, 0x00, 0x00, 0x00, 0x00, 0x00, 0x00, 0x00, 0x00, 0x00, 0x00, 0x00, 0x00, 
  0x00, 0x00, 0x00, 0x00, 0x00, 0xfc, 0xfc, 0xfc, 0x80, 0x80, 0x80, 0x80, 0x80, 0xfc, 0xfc, 0xfc, 
  0x00, 0x00, 0x00, 0x80, 0xf0, 0xfc, 0x1c, 0x7c, 0xf8, 0xe0, 0x00, 0x00, 0x00, 0xc0, 0xf0, 0xf8, 
  0x38, 0x1c, 0x0c, 0x0c, 0x0c, 0x0c, 0x00, 0x00, 0xfc, 0xfc, 0xfc, 0x80, 0xe0, 0xf0, 0x7c, 0x1c, 
  0x0c, 0x04, 0x00, 0x00, 0x00, 0x00, 0x00, 0x0c, 0x0c, 0x0c, 0xfc, 0xfc, 0x0c, 0x0c, 0x0c, 0x0c, 
  0x00, 0xfc, 0xfc, 0xfc, 0x80, 0x80, 0x80, 0x80, 0x80, 0xfc, 0xfc, 0xfc, 0x00, 0x0c, 0xfc, 0xfc, 
  0xfc, 0x0c, 0x00, 0x70, 0xf8, 0xfc, 0xcc, 0x8c, 0x8c, 0x0c, 0x08, 0x00, 0x00, 0x00, 0x00, 0x00, 
  0x00, 0x00, 0x00, 0x00, 0x00, 0x00, 0x00, 0x00, 0x00, 0x00, 0x00, 0x00, 0x00, 0x00, 0x00, 0x00, 
  0x00, 0x00, 0x00, 0x00, 0x00, 0x00, 0x00, 0x00, 0x00, 0x00, 0x00, 0x00, 0x00, 0x00, 0x00, 0x00, 
  0x00, 0x00, 0x00, 0x00, 0x00, 0x3f, 0x3f, 0x3f, 0x01, 0x01, 0x01, 0x01, 0x01, 0x3f, 0x3f, 0x3f, 
  0x00, 0x30, 0x3e, 0x3f, 0x07, 0x06, 0x06, 0x06, 0x07, 0x1f, 0x3f, 0x38, 0x00, 0x07, 0x0f, 0x1f, 
  0x1c, 0x38, 0x30, 0x30, 0x30, 0x30, 0x00, 0x00, 0x3f, 0x3f, 0x3f, 0x01, 0x03, 0x0f, 0x1e, 0x3c, 
  0x30, 0x20, 0x00, 0x00, 0x00, 0x00, 0x00, 0x00, 0x00, 0x00, 0x3f, 0x3f, 0x00, 0x00, 0x00, 0x00, 
  0x00, 0x3f, 0x3f, 0x3f, 0x01, 0x01, 0x01, 0x01, 0x01, 0x3f, 0x3f, 0x3f, 0x00, 0x30, 0x3f, 0x3f, 
  0x3f, 0x30, 0x00, 0x18, 0x30, 0x31, 0x31, 0x33, 0x3f, 0x1f, 0x1e, 0x00, 0x00, 0x00, 0x00, 0x00, 
  0x00, 0x00, 0x00, 0x00, 0x00, 0x00, 0x00, 0x00, 0x00, 0x00, 0x00, 0x00, 0x00, 0x00, 0x00, 0x00, 
  0x00, 0x00, 0x00, 0x00, 0x00, 0x00, 0x00, 0x00, 0x00, 0x00, 0x00, 0x00, 0x00, 0x00, 0x00, 0x00, 
  0x00, 0x00, 0x00, 0x00, 0x00, 0x00, 0x00, 0x00, 0xfc, 0xfc, 0xfc, 0x8c, 0x8c, 0xdc, 0xfc, 0x78, 
  0x10, 0x00, 0x00, 0x00, 0xc0, 0xf8, 0x7c, 0x1c, 0xfc, 0xf8, 0xc0, 0x00, 0x00, 0x00, 0x00, 0xfc, 
  0xfc, 0x0c, 0x0c, 0x0c, 0x0c, 0x1c, 0xf8, 0xf8, 0xe0, 0x00, 0xc0, 0xf0, 0xf8, 0x38, 0x1c, 0x0c, 
  0x8c, 0x8c, 0x8c, 0x9c, 0x80, 0x00, 0x00, 0xfc, 0xfc, 0x8c, 0x8c, 0x8c, 0x8c, 0x0c, 0x00, 0x00, 
  0x00, 0x00, 0x00, 0x00, 0xfc, 0xfc, 0xfc, 0x00, 0x00, 0x00, 0xfc, 0xfc, 0x00, 0x00, 0x00, 0xfc, 
  0xfc, 0xfc, 0x00, 0x00, 0x00, 0xfc, 0xfc, 0x00, 0x00, 0x00, 0x00, 0x00, 0x00, 0x00, 0x00, 0x00, 
  0x00, 0x00, 0x00, 0x00, 0x00, 0x00, 0x00, 0x00, 0x00, 0x00, 0x00, 0x00, 0x00, 0x00, 0x00, 0x00, 
  0x00, 0x00, 0x00, 0x00, 0x00, 0x00, 0x00, 0x00, 0x00, 0x00, 0x00, 0x00, 0x00, 0x00, 0x00, 0x00, 
  0x00, 0x00, 0x00, 0x00, 0x00, 0x00, 0x00, 0x00, 0x3f, 0x3f, 0x3f, 0x31, 0x31, 0x31, 0x3f, 0x1f, 
  0x0e, 0x00, 0x38, 0x3e, 0x3f, 0x07, 0x06, 0x06, 0x06, 0x07, 0x3f, 0x3e, 0x30, 0x00, 0x00, 0x3f, 
  0x3f, 0x30, 0x30, 0x30, 0x30, 0x18, 0x1f, 0x0f, 0x07, 0x00, 0x03, 0x0f, 0x1f, 0x18, 0x38, 0x30, 
  0x31, 0x31, 0x3f, 0x1f, 0x1f, 0x00, 0x00, 0x3f, 0x3f, 0x31, 0x31, 0x31, 0x31, 0x30, 0x00, 0x00, 
  0x00, 0x00, 0x00, 0x00, 0x3b, 0x3b, 0x3b, 0x00, 0x00, 0x00, 0x3b, 0x3b, 0x00, 0x00, 0x00, 0x3b, 
  0x3b, 0x3b, 0x00, 0x00, 0x00, 0x3b, 0x3b, 0x00, 0x00, 0x00, 0x00, 0x00, 0x00, 0x00, 0x00, 0x00, 
  0x00, 0x00, 0x00, 0x00, 0x00, 0x00, 0x00, 0x00, 0x00, 0x00, 0x00, 0x00, 0x00, 0x00, 0x00, 0x00
};

// 'custom', 128x32px
const unsigned char dc29Bitmap [] PROGMEM = {
  0x00, 0x00, 0x00, 0x00, 0x00, 0x00, 0x00, 0x00, 0x00, 0x00, 0x00, 0x00, 0x00, 0x00, 0x00, 0x00, 
  0x00, 0x00, 0x00, 0x00, 0x00, 0x00, 0xe0, 0xe0, 0xe0, 0xe0, 0xe0, 0xe0, 0xe0, 0xe0, 0xe0, 0xe0, 
  0xe0, 0xe0, 0xc0, 0xc0, 0x80, 0x00, 0x00, 0x00, 0x00, 0x00, 0x00, 0x00, 0x00, 0x00, 0x00, 0x80, 
  0xc0, 0xc0, 0xc0, 0xe0, 0xe0, 0xe0, 0xe0, 0xe0, 0xc0, 0xc0, 0xc0, 0x80, 0x00, 0x00, 0x00, 0x00, 
  0x00, 0x00, 0x00, 0x00, 0x00, 0x00, 0x00, 0x00, 0x00, 0x00, 0x00, 0x00, 0x80, 0xc0, 0xc0, 0xc0, 
  0xe0, 0xe0, 0xe0, 0xe0, 0xe0, 0xc0, 0xc0, 0x80, 0x00, 0x00, 0x00, 0x00, 0x00, 0x00, 0x80, 0xc0, 
  0xc0, 0xe0, 0xe0, 0xe0, 0xe0, 0xc0, 0xc0, 0x80, 0x00, 0x00, 0x00, 0x00, 0x00, 0x00, 0x00, 0x00, 
  0x00, 0x00, 0x00, 0x00, 0x00, 0x00, 0x00, 0x00, 0x00, 0x00, 0x00, 0x00, 0x00, 0x00, 0x00, 0x00, 
  0x00, 0x00, 0x00, 0x00, 0x00, 0x00, 0x00, 0x00, 0x00, 0x00, 0x00, 0x00, 0x00, 0x00, 0x00, 0x00, 
  0x00, 0x00, 0x00, 0x00, 0x00, 0x00, 0xff, 0xff, 0xff, 0xff, 0x01, 0x01, 0x01, 0x01, 0x01, 0x01, 
  0x01, 0x03, 0x07, 0x0f, 0xff, 0xff, 0xfe, 0xf8, 0x00, 0x00, 0x00, 0x00, 0xf8, 0xfe, 0xff, 0xff, 
  0x0f, 0x07, 0x03, 0x01, 0x01, 0x01, 0x01, 0x01, 0x03, 0x07, 0x1f, 0x1f, 0x0f, 0x0e, 0x00, 0x00, 
  0x00, 0x00, 0x00, 0x00, 0x00, 0x00, 0x00, 0x00, 0x00, 0x00, 0x00, 0x06, 0x0f, 0x0f, 0x0f, 0x03, 
  0x01, 0x01, 0x01, 0x81, 0xc3, 0xff, 0xff, 0xff, 0x3e, 0x00, 0x00, 0x00, 0x7e, 0xff, 0xff, 0xff, 
  0xc3, 0x81, 0x81, 0x81, 0x81, 0xc3, 0xff, 0xff, 0xff, 0xfe, 0xc0, 0x00, 0x00, 0x00, 0x00, 0x00, 
  0x00, 0x00, 0x00, 0x00, 0x00, 0x00, 0x00, 0x00, 0x00, 0x00, 0x00, 0x00, 0x00, 0x00, 0x00, 0x00, 
  0x00, 0x00, 0x00, 0x00, 0x00, 0x00, 0x00, 0x00, 0x00, 0x00, 0x00, 0x00, 0x00, 0x00, 0x00, 0x00, 
  0x00, 0x00, 0x00, 0x00, 0x00, 0x00, 0xff, 0xff, 0xff, 0xff, 0x80, 0x80, 0x80, 0x80, 0x80, 0x80, 
  0x80, 0xc0, 0xc0, 0xf0, 0xff, 0xff, 0x7f, 0x1f, 0x00, 0x00, 0x00, 0x00, 0x1f, 0x7f, 0xff, 0xff, 
  0xf0, 0xe0, 0xc0, 0x80, 0x80, 0x80, 0x80, 0x80, 0xc0, 0xe0, 0xf8, 0xfc, 0xf8, 0x38, 0x08, 0x00, 
  0x00, 0x00, 0x00, 0x00, 0x00, 0x00, 0x00, 0x00, 0x00, 0x00, 0x00, 0x00, 0xc0, 0xe0, 0xf0, 0xf8, 
  0xbc, 0x9e, 0x8f, 0x8f, 0x87, 0x83, 0x81, 0x80, 0x80, 0x00, 0x00, 0x00, 0x00, 0xc1, 0xe3, 0xe3, 
  0xe7, 0x87, 0x87, 0x87, 0x83, 0xc3, 0xff, 0xff, 0xff, 0x7f, 0x07, 0x00, 0x00, 0x00, 0x00, 0x00, 
  0x00, 0x00, 0x00, 0x00, 0x00, 0x00, 0x00, 0x00, 0x00, 0x00, 0x00, 0x00, 0x00, 0x00, 0x00, 0x00, 
  0x00, 0x00, 0x00, 0x00, 0x00, 0x00, 0x00, 0x00, 0x00, 0x00, 0x00, 0x00, 0x00, 0x00, 0x00, 0x00, 
  0x00, 0x00, 0x00, 0x00, 0x00, 0x00, 0x07, 0x07, 0x07, 0x07, 0x07, 0x07, 0x07, 0x07, 0x07, 0x07, 
  0x07, 0x03, 0x03, 0x03, 0x01, 0x00, 0x00, 0x00, 0x00, 0x00, 0x00, 0x00, 0x00, 0x00, 0x00, 0x01, 
  0x03, 0x03, 0x03, 0x07, 0x07, 0x07, 0x07, 0x07, 0x03, 0x03, 0x03, 0x01, 0x00, 0x00, 0x00, 0x00, 
  0x00, 0x00, 0x00, 0x00, 0x00, 0x00, 0x00, 0x00, 0x00, 0x00, 0x00, 0x07, 0x07, 0x07, 0x07, 0x07, 
  0x07, 0x07, 0x07, 0x07, 0x07, 0x07, 0x07, 0x07, 0x07, 0x00, 0x00, 0x00, 0x00, 0x00, 0x03, 0x03, 
  0x07, 0x07, 0x07, 0x07, 0x07, 0x03, 0x03, 0x03, 0x01, 0x00, 0x00, 0x00, 0x00, 0x00, 0x00, 0x00, 
  0x00, 0x00, 0x00, 0x00, 0x00, 0x00, 0x00, 0x00, 0x00, 0x00, 0x00, 0x00, 0x00, 0x00, 0x00, 0x00
};
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
void loop() {

  // Check the button for activity
  DoButton();

  // Change the menu if button has been pushed
  MenuChange();

  //Reinitialize menu variables
  OldMenuVar = NewMenuVar;

}


////////////////////////////////////////////////////////////////
//////////  OTHER FUNCTIONS
////////////////////////////////////////////////////////////////

void secret1(){
  //colorWipe(strip.Color(neoPixelIntensity, 0, 0), 0);
  /*
  strip.setPixelColor(0, strip.Color(neoPixelIntensity,0,0)); // Moderately bright green color.
  strip.show(); // This sends the updated pixel color to the hardware.
  delay(1000);
  colorWipe(strip.Color(0, 0, 0), 0);
  */

/*

    OzOled.setCursorXY(0,0);   
    OzOled.printString("KEY");  
    OzOled.setCursorXY(0,2);  
    OzOled.printString("makeithackin");  
    delay(3000);
  */
  
  /*
  dot();dot();dot();
  delay(300);
  dash();dash();dash();
  delay(300);
  dot();dot();dot();

  */
  
  /*
  OzOled.drawBitmap(QRCodeBitmap, 0, 0, 16, 8); 
   */
    
    OzOled.clearDisplay(); 
    OzOled.setCursorXY(0,0);   
    OzOled.printString("   YOU HAVE  ");  
    OzOled.setCursorXY(0,1);   
    OzOled.printString(" UNLOCKED A KEY!");  
    OzOled.setCursorXY(0,2);  
    OzOled.printString("   IT IS... ");  
    delay(3000);

    OzOled.clearDisplay(); 
    OzOled.setCursorXY(0,0);   
    OzOled.printString("THE TITLE OF MY ");  
    OzOled.setCursorXY(0,1);   
    OzOled.printString("  MOST VIEWED");
    OzOled.setCursorXY(0,2);  
    OzOled.printString(" TIKTOK VIDEO ");  
    delay(3000);
  
}

void dot(){
  strip.setPixelColor(0, strip.Color(neoPixelIntensity,neoPixelIntensity,neoPixelIntensity)); // Moderately bright green color.
  strip.show(); // This sends the updated pixel color to the hardware.
  delay(100);
  strip.setPixelColor(0, strip.Color(0,0,0)); // Moderately bright green color.
  strip.show(); // This sends the updated pixel color to the hardware.
  delay(100);
}

void dash(){
  strip.setPixelColor(0, strip.Color(neoPixelIntensity,neoPixelIntensity,neoPixelIntensity)); // Moderately bright green color.
  strip.show(); // This sends the updated pixel color to the hardware.
  delay(300);
  strip.setPixelColor(0, strip.Color(0,0,0)); // Moderately bright green color.
  strip.show(); // This sends the updated pixel color to the hardware.
  delay(300);  
}

///////////////////////////////////////////////////////////////////////////////////////////////////////////////////

void secret2(){

  OzOled.clearDisplay(); 
  OzOled.setCursorXY(0,0);   
  OzOled.printString("   YOU HAVE  ");  
  OzOled.setCursorXY(0,1);   
  OzOled.printString(" UNLOCKED A KEY!");  
  //OzOled.setCursorXY(0,2);  
  //OzOled.printString(" WATCH THE  ");  
  //delay(3000);
    
  dot();dash();
  delay(morseCodeDelay);
  dash();dot();dot();dot();
  delay(morseCodeDelay);
  dot();dash();
  delay(morseCodeDelay);
  dash();dot();dot();
  delay(morseCodeDelay);
  dot();dash();dash();dash();dash();
  delay(morseCodeDelay);
  dash();dot();dot();
  delay(morseCodeDelay);
  dot();
  delay(morseCodeDelay);
  dot();dash();
  delay(morseCodeDelay);
}


///////////////////////////////////////////////////////////////////////////////////////////////////////////////////

void secret3(){

}


///////////////////////////////////////////////////////////////////////////////////////////////////////////////////

void secret4(){
  
}

///////////////////////////////////////////////////////////////////////////////////////////////////////////////////

void secret5(){
  //colorWipe(strip.Color(neoPixelIntensity, 0, neoPixelIntensity), 0);
  //delay(1000);
  //colorWipe(strip.Color(0, 0, 0), 0);
}

///////////////////////////////////////////////////////////////////////////////////////////////////////////////////


void goToAwardMenu(){
 
  OzOled.clearDisplay();

  if (badgeType == 0){
    //DEVELOPER MODE
    OzOled.setCursorXY(0,1);   
    OzOled.printString("    DEVELOPER ");  
    OzOled.setCursorXY(0,3);  
    OzOled.printString("   SECRET MODE ");  
  }
  else if (badgeType == 1){
    //SHENETWORKS
    //OzOled.drawBitmap(shenetworksBitmap, 0, 0, 16, 8);              
  }
  else if (badgeType == 2){
    //BYT3BOY 
    //OzOled.drawBitmap(byt3boyBitmap, 0, 0, 16, 8);   
  }
  else if (badgeType == 3){
    //LLAMARUNNER
    //OzOled.drawBitmap(llamarunnerBitmap, 0, 0, 16, 8);   
  }
  else if (badgeType == 4){
    //CYBERPORTER
   // OzOled.drawBitmap(cyberporterBitmap, 0, 0, 16, 8);
  }
  else if (badgeType == 5){
    //CUSTOM TEXT SCREEN
    OzOled.setCursorXY(0,0);   
    OzOled.printString(customLine1);  
    OzOled.setCursorXY(0,2);  
    OzOled.printString(customLine2);  
  }
  else if (badgeType == 6){
    //MAKEITHACKIN IMAGE
    OzOled.drawBitmap(MakeItHackinBitmap, 0, 0, 16, 8);
  }
  else if (badgeType == 7){
    //DC29 IMAGE
    OzOled.drawBitmap(dc29Bitmap, 0, 0, 16, 8);
  }  
  else if (badgeType == 8){
    //CUSTOM IMAGE
    OzOled.drawBitmap(customBitmap, 0, 0, 16, 8);
  }
  else {
    //do nothing
    //PLACE HOLDER
  }
        
}

///////////////////////////////////////////////////////////////////////////////////////////////////////////////////

void DoButton(){

    // Get current button state.
  newState = digitalRead(BUTTON_PIN);

  // Check if state changed from high to low (button press).
  if (newState == LOW && oldState == HIGH) {
    // Short delay to debounce button.
    delay(20);
    // Check if button is still low after debounce.
    newState = digitalRead(BUTTON_PIN);
    if (newState == LOW) {
      NewMenuVar = OldMenuVar + 1;
      OzOled.clearDisplay();  
    }
    else {
      NewMenuVar = OldMenuVar;
    }
    if (NewMenuVar == MenuCount+1) {
       NewMenuVar = 1;
       }      
  }

  // Set the last button state to the old state.
  oldState = newState;

}

///////////////////////////////////////////////////////////////////////////////////////////////////////////////////

void MenuChange() {
  
         if (NewMenuVar == MenuCount+1) {
              NewMenuVar = 1;
             }
         
         if (NewMenuVar == 0) {
            NewMenuVar = MenuCount;
          }
      
        if (NewMenuVar == 1)
          {
              OzOled.setCursorXY(0,0);   
              OzOled.printString("   MAIN MENU");  
              OzOled.setCursorXY(0,2);  
              OzOled.printString(" PRESS BUTTON TO ");  
              OzOled.setCursorXY(0,3);  
              OzOled.printString(" TEST COMPONENTS "); 
              //rainbow(20);
          } 
        else if (NewMenuVar == 2)
          {
            showLightSensor();
          }     
        else if (NewMenuVar == 3)
          {
            nightLight();
          }     
        else if (NewMenuVar == 4)
          {
            //showLightSensor();
            OzOled.setCursorXY(0,0);   
            OzOled.printString(" STARTING ");
            OzOled.setCursorXY(0,1); 
            OzOled.printString(" DEMO MODE... ");
            OzOled.setCursorXY(0,2);   
            OzOled.printString(" PRESS RESET ");
            OzOled.setCursorXY(0,3);   
            OzOled.printString(" TO EXIT ");
            colorWipe(strip.Color(0, 0, 0), 0);    // Black/off
            delay(1000);
            StartDemoMode();
          }
           else 
              {
               // OnOffBool1 = 0;
              }  

  //delay(100);        
}

///////////////////////////////////////////////////////////////////////////////////////////////////////////////////

void StartDemoMode(){

  OzOled.clearDisplay();

  OzOled.drawBitmap(MakeItHackinBitmap, 0, 0, 16, 8);

  //theaterChase(strip.Color(0, 0, neoPixelIntensity), theaterChaseDelay); // blue
  colorWipe(strip.Color(neoPixelIntensity, 0, neoPixelIntensity), 350);
  colorWipe(strip.Color(0, 0, 0), 0);    // Black/off

  OzOled.drawBitmap(dc29Bitmap, 0, 0, 16, 8);
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

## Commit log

2021-07-11 Create BOM
2021-07-15 Update BOM

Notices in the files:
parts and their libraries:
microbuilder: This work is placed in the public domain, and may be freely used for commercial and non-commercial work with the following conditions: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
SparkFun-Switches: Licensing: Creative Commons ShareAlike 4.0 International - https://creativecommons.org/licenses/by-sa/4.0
